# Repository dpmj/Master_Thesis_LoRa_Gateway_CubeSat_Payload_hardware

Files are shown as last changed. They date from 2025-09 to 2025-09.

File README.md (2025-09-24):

# Hardware design of a LoRa Gateway payload for CubeSat.

This repository contains the hardware design files from my first Master's Thesis in Electronic Systems Engineering at the Polytechnic University of Valencia, Spain, 2024. The thesis covers developing a LoRa communications payload for a CubeSat in Low Earth Orbit (LEO). The payload consists of two mPCIe LoRa gateway modules and a CubeSat-PC/104 motherboard, which serves as the electrical and mechanical interface with the rest of the satellite. An Electrical Ground Support Equipment (EGSE) auxiliary board provides test hardware for the payload by emulating interaction with the CubeSat. It also acts as a LoRa end-device to test the performance of the communications system.

This project has been superseded and continued in my other master's thesis: [Hardware design of a LoRa Gateway and in-orbit computing payload for CubeSat](https://github.com/dpmj/masters-thesis-lora-gateway-compute-module-cubesat-payload-pcb).

Third-party desing elements included in this repository are subject to the copyright of their respective owners.

```bibtex
@phdthesis{dpmj-master-thesis-2024,
    author = {{Del Pino Mena}, Juan},
    title = {Development of a {LoRa}-based communications payload for {CubeSat}},
    school = {Universitat Politècnica de València},
    year = {2024},
    month = {9},
    address = {València, Spain},
    type = {Master's thesis},
    url = {https://riunet.upv.es/handle/10251/209572},
    doi = {https://doi.org/10.5281/zenodo.13935118}
}
```

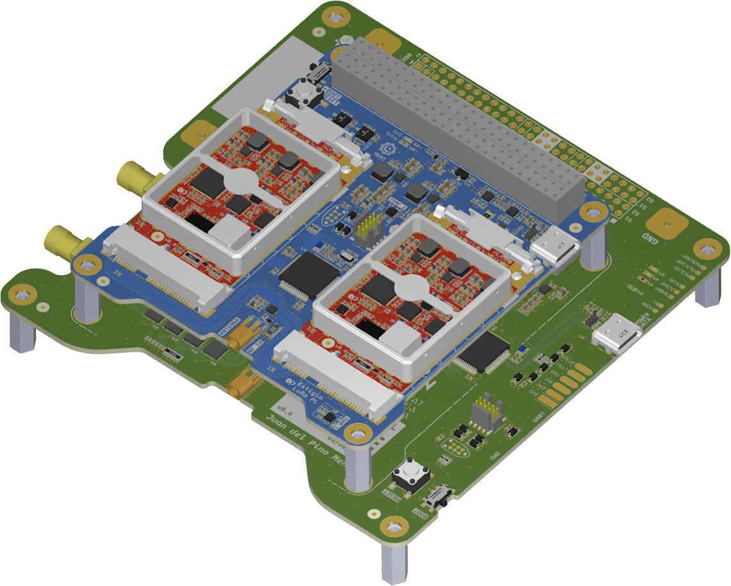
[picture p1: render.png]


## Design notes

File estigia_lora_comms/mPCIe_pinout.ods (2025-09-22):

Top side |  |  | Bottom side
N.º | PCIE | LORA SOM | N.º | PCIE | LORA SOM
1 | WAKE# | GND | 2 | 3.3V | 5V
3 | COEX1 | RFIO | 4 | GND | GND
5 | COEX2 | GND | 6 | 1.5V | NC
7 | CLKREQ# | NC | 8 | UIM_PWR | NC
9 | GND | GND | 10 | UIM_DATA | NC
11 | REFCLK- | NC | 12 | UIM_CLK | RADIO_CLK_OUT
13 | REFCLK+ | NC | 14 | UIM_RESET | RESET
15 | N/C or GND | GND | 16 | UIM_VPP | ENABLE
Mechanical key
17 | UIM_C8_RSV | NC | 18 | GND | GND
19 | UIM_C4_RSV | NC | 20 | W_DISABLE# | NC
21 | GND | GND | 22 | PERST# | NC
23 | PERn0 | NC | 24 | 3.3V | 5V
25 | PERp0 | NC | 26 | GND | GND
27 | GND | GND | 28 | +1.5V | NC
29 | GND | GND | 30 | SMB_CLK | I2C_SCL
31 | PETn0 | NC | 32 | SMB_DATA | I2C_SDA
33 | PETp0 | NC | 34 | GND | GND
35 | GND | GND | 36 | USB_D- | NC
37 | GND | GND | 38 | USB_D+ | NC
39 | 3.3V | 5V | 40 | GND | GND
41 | 3.3V | 5V | 42 | LED_WWAN# | PG1V2
43 | GND | GND | 44 | LED_WLAN# | PG3V3
45 | Reserved* | MCU_SPI_CLK | 46 | LED_WPAN# | PG3V9
47 | Reserved* | MCU_SPI_MISO | 48 | +1.5V | NC
49 | Reserved* | MCU_SPI_MOSI | 50 | GND | GND
51 | Reserved* | MCU_SPI_NSS | 52 | +3.3V | 5V

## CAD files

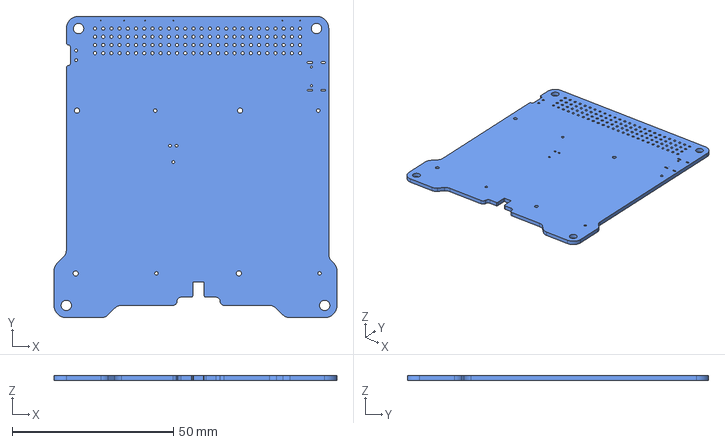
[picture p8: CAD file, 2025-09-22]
carrier/outputs/3D STEP/carrier_pcb_only.step
87.6 x 93.3 x 1.59 mm

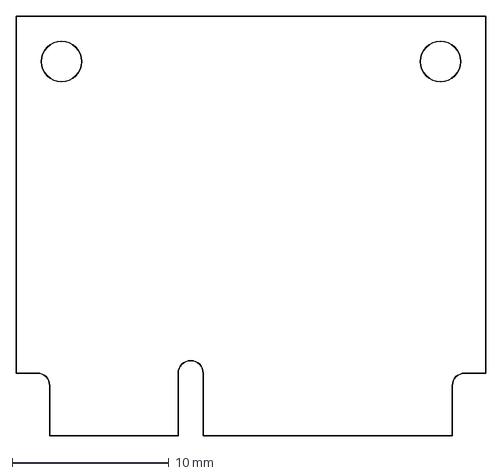
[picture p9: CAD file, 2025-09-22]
estigia_lora_comms/assets/templates/mini-pcie-card-template-master/MiniPCIe.dxf
30.0 x 26.8 mm

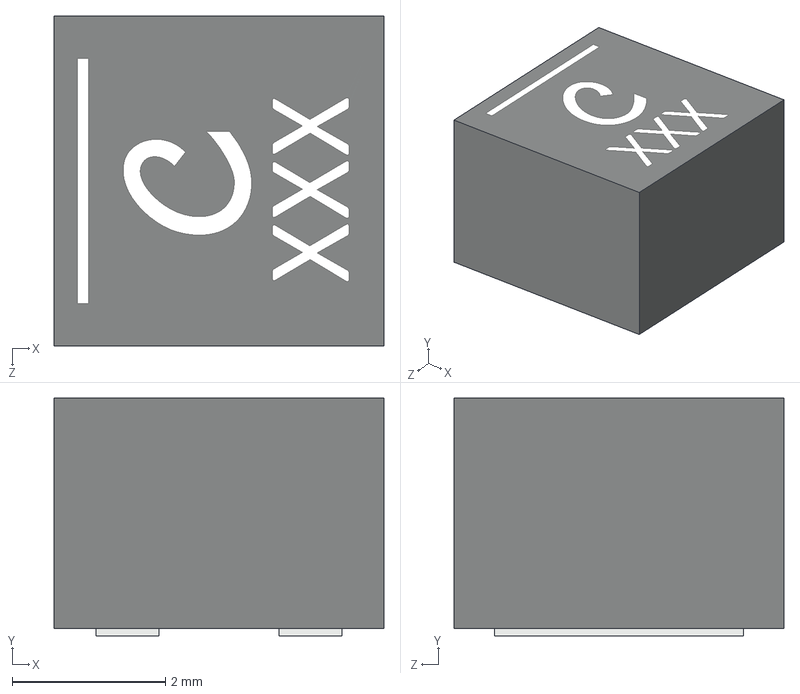
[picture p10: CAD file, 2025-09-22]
estigia_lora_comms/library-common/models/Coilcraft-XGL4030/Coilcraft-XGL4030.step
4.30 x 3.10 x 4.30 mm

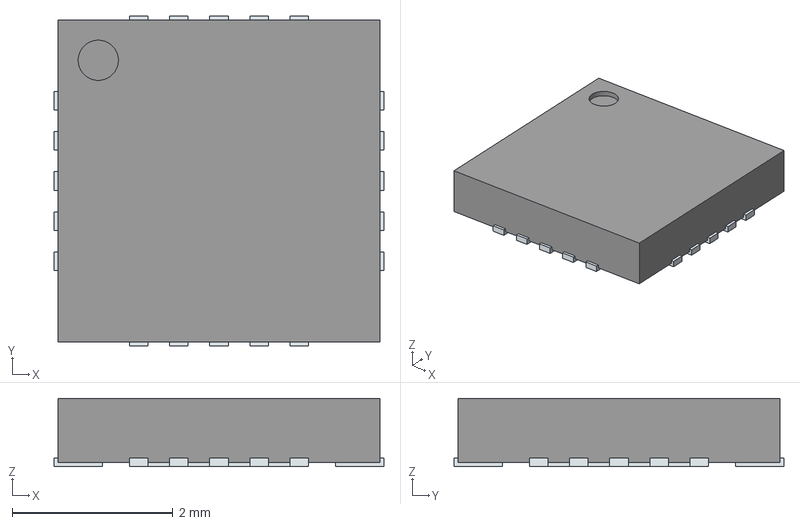
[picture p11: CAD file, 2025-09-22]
estigia_lora_comms/library-common/models/DG983-2/DG983-2.stp
4.10 x 4.10 x 0.85 mm
ThermalPin
PinsArrayLR
PinsArrayTB

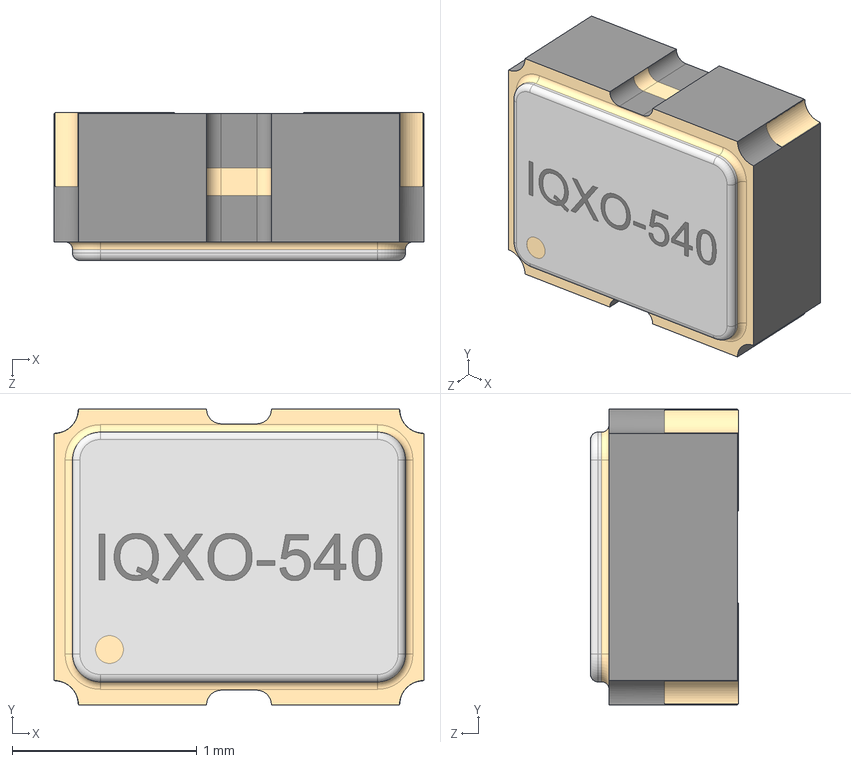
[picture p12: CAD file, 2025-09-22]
estigia_lora_comms/library-common/models/FT2MNTUM/IQXO-540.step
2.00 x 1.60 x 0.8 mm

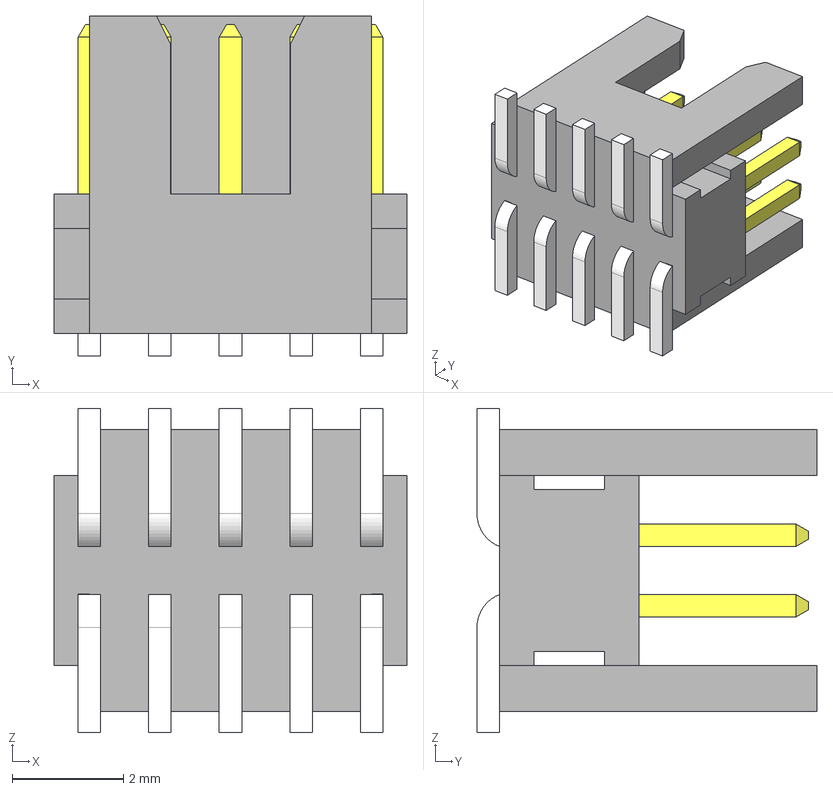
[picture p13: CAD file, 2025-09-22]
estigia_lora_comms/library-common/models/FTSH-105/FTSH-105-01-L-DV.stp
6.35 x 6.12 x 5.84 mm
_FTSH-105-01-F-DV-K_body
_FTSH-105-01-F-DV-K_pins1
_FTSH-105-01-F-DV-K_pins2

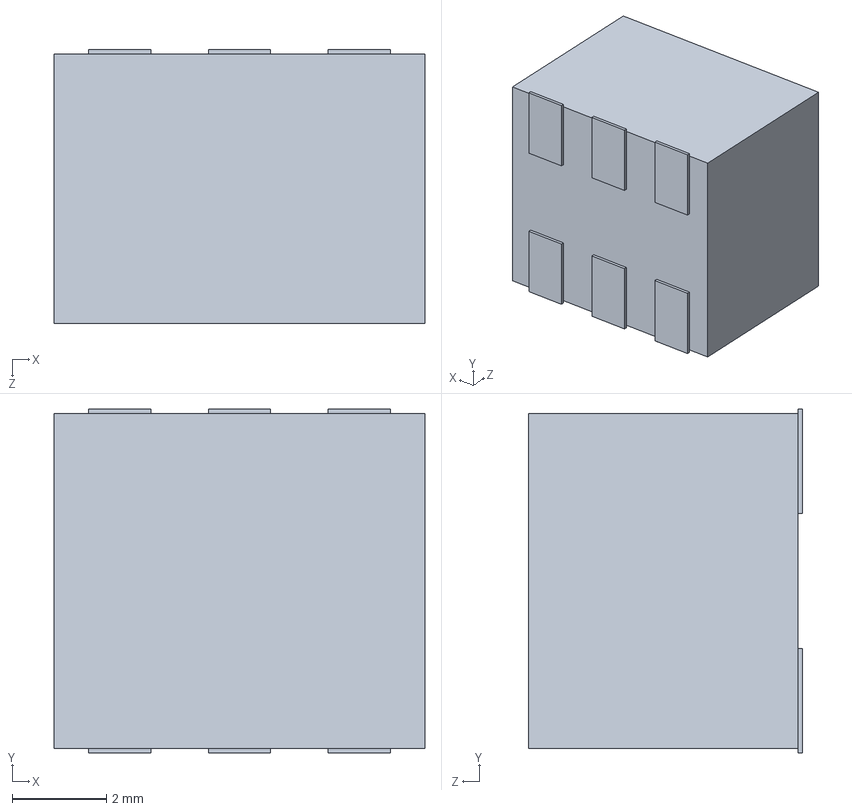
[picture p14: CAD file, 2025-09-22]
estigia_lora_comms/library-common/models/JPS-2-1N+/JPS-2-1N+.STEP
7.87 x 7.29 x 5.82 mm

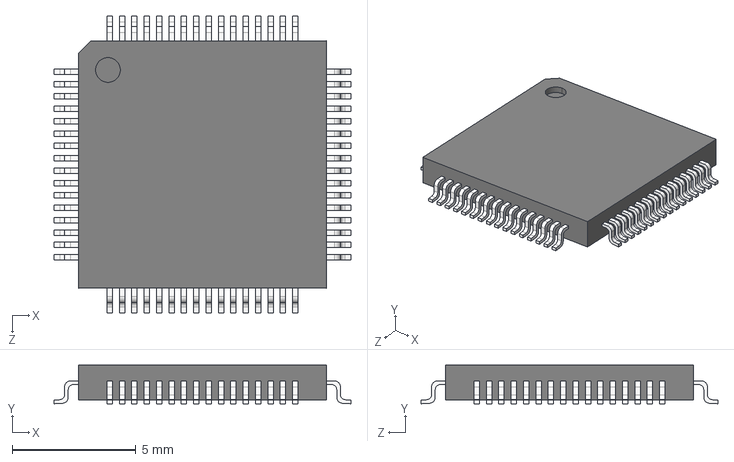
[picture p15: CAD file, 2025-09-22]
estigia_lora_comms/library-common/models/LQFP64/LQFP64.step
12.0 x 1.56 x 12.0 mm

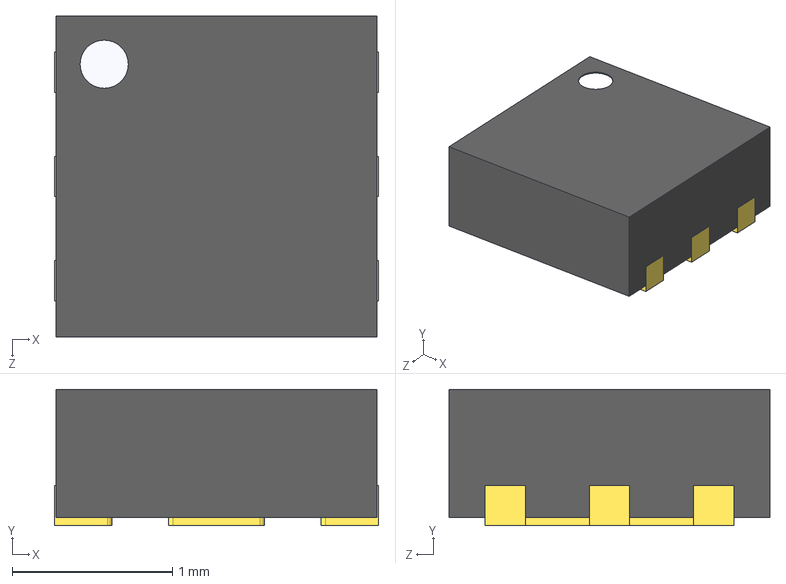
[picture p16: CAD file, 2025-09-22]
estigia_lora_comms/library-common/models/MC1630/MC1630.step
2.02 x 0.85 x 2.00 mm

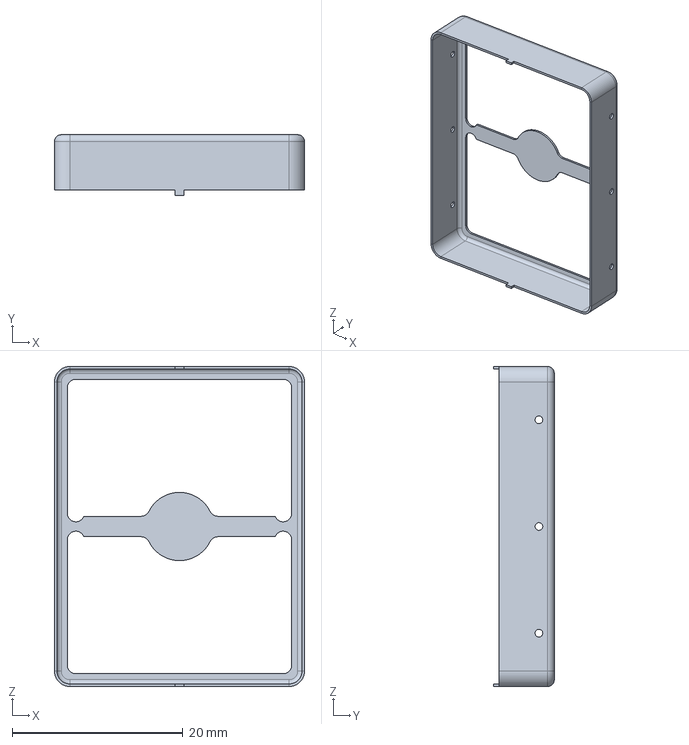
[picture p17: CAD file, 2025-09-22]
estigia_lora_comms/library-common/models/MS375-10F/ms375-10f.stp
29.3 x 7.10 x 37.5 mm

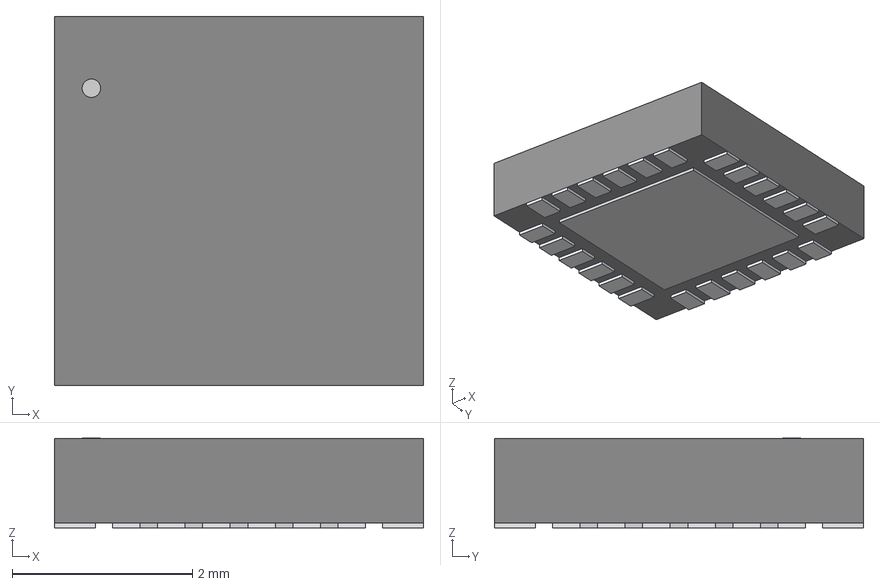
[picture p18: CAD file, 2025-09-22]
estigia_lora_comms/library-common/models/QFN-24/QFN_0IMLTRT_SEM.step
4.09 x 4.09 x 0.993 mm

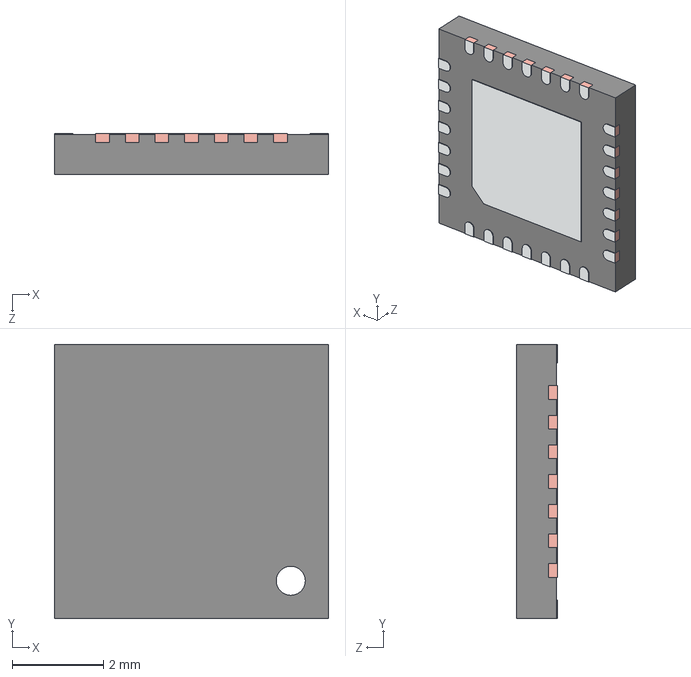
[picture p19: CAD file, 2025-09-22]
estigia_lora_comms/library-common/models/QFN-28/QFN28_0_65.step
6.00 x 6.00 x 0.9 mm

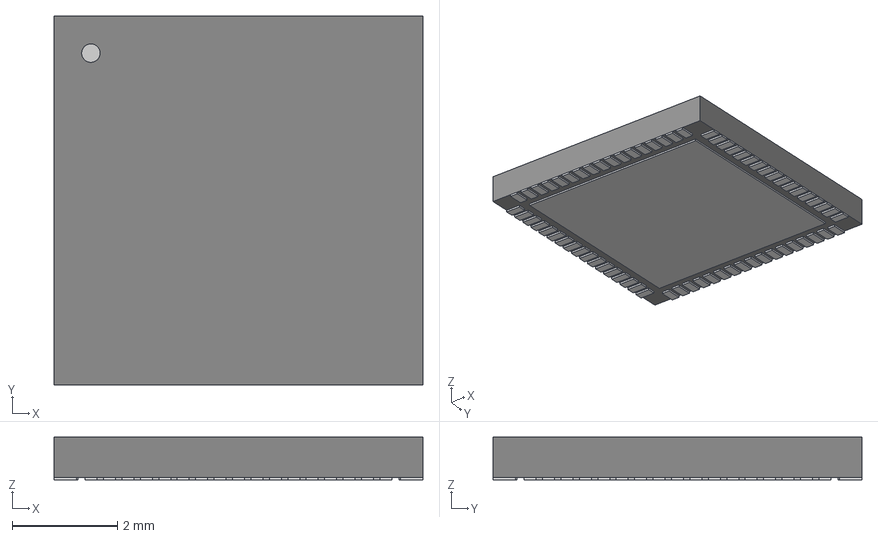
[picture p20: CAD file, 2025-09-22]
estigia_lora_comms/library-common/models/QFN-68/QFN68_7X7_SEM.step
7.01 x 7.01 x 0.815 mm

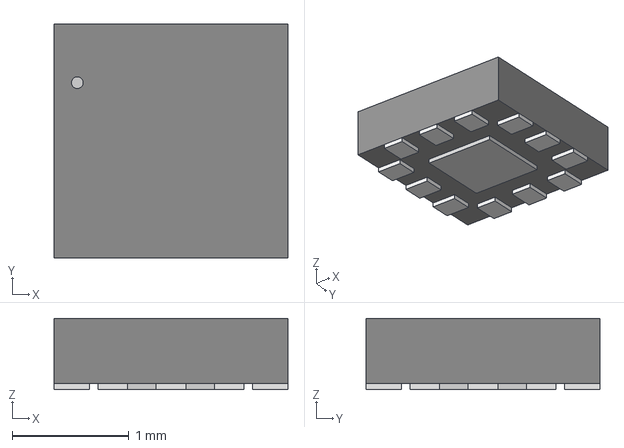
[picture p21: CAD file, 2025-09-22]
estigia_lora_comms/library-common/models/SKY13330_397LF/QFN_330-397LF_SKY.step
2.01 x 2.01 x 0.612 mm

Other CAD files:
estigia_lora_comms/library-common/models/TXB0104NMN/TXB0104NMNR2.SLDASM
estigia_lora_comms/library-common/models/TXB0104NMN/TXB0104NMNR3.SLDASM
estigia_lora_comms/library-common/models/SMA/sma_straight.stp
estigia_lora_comms/library-common/models/SOT-23-8-INA232BIDDFR/INA232BIDDFR.stp
estigia_lora_comms/library-common/models/JPS-2-1N+/Body.stp.STEP
estigia_lora_comms/library-common/models/JPS-2-1N+/JPS-2-1N+.SLDASM
estigia_lora_comms/library-common/models/JPS-2-1N+/JPS-2-1N+.SLDPRT
estigia_lora_comms/library-common/models/JPS-2-1N+/JPS-2-1N+.stp
estigia_lora_comms/library-common/models/JPS-2-1N+/JPS-2-1N+.stp.STEP
estigia_lora_comms/library-common/models/JPS-2-1N+/JPS-2-1N+_2.SLDPRT
estigia_lora_comms/library-common/models/JPS-2-1N+/JPS-2-1N+_2.STEP
estigia_lora_comms/library-common/models/JPS-2-1N+/Pins.stp.STEP
estigia_lora_comms/library-common/models/MMCX/66012202111305.stp
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

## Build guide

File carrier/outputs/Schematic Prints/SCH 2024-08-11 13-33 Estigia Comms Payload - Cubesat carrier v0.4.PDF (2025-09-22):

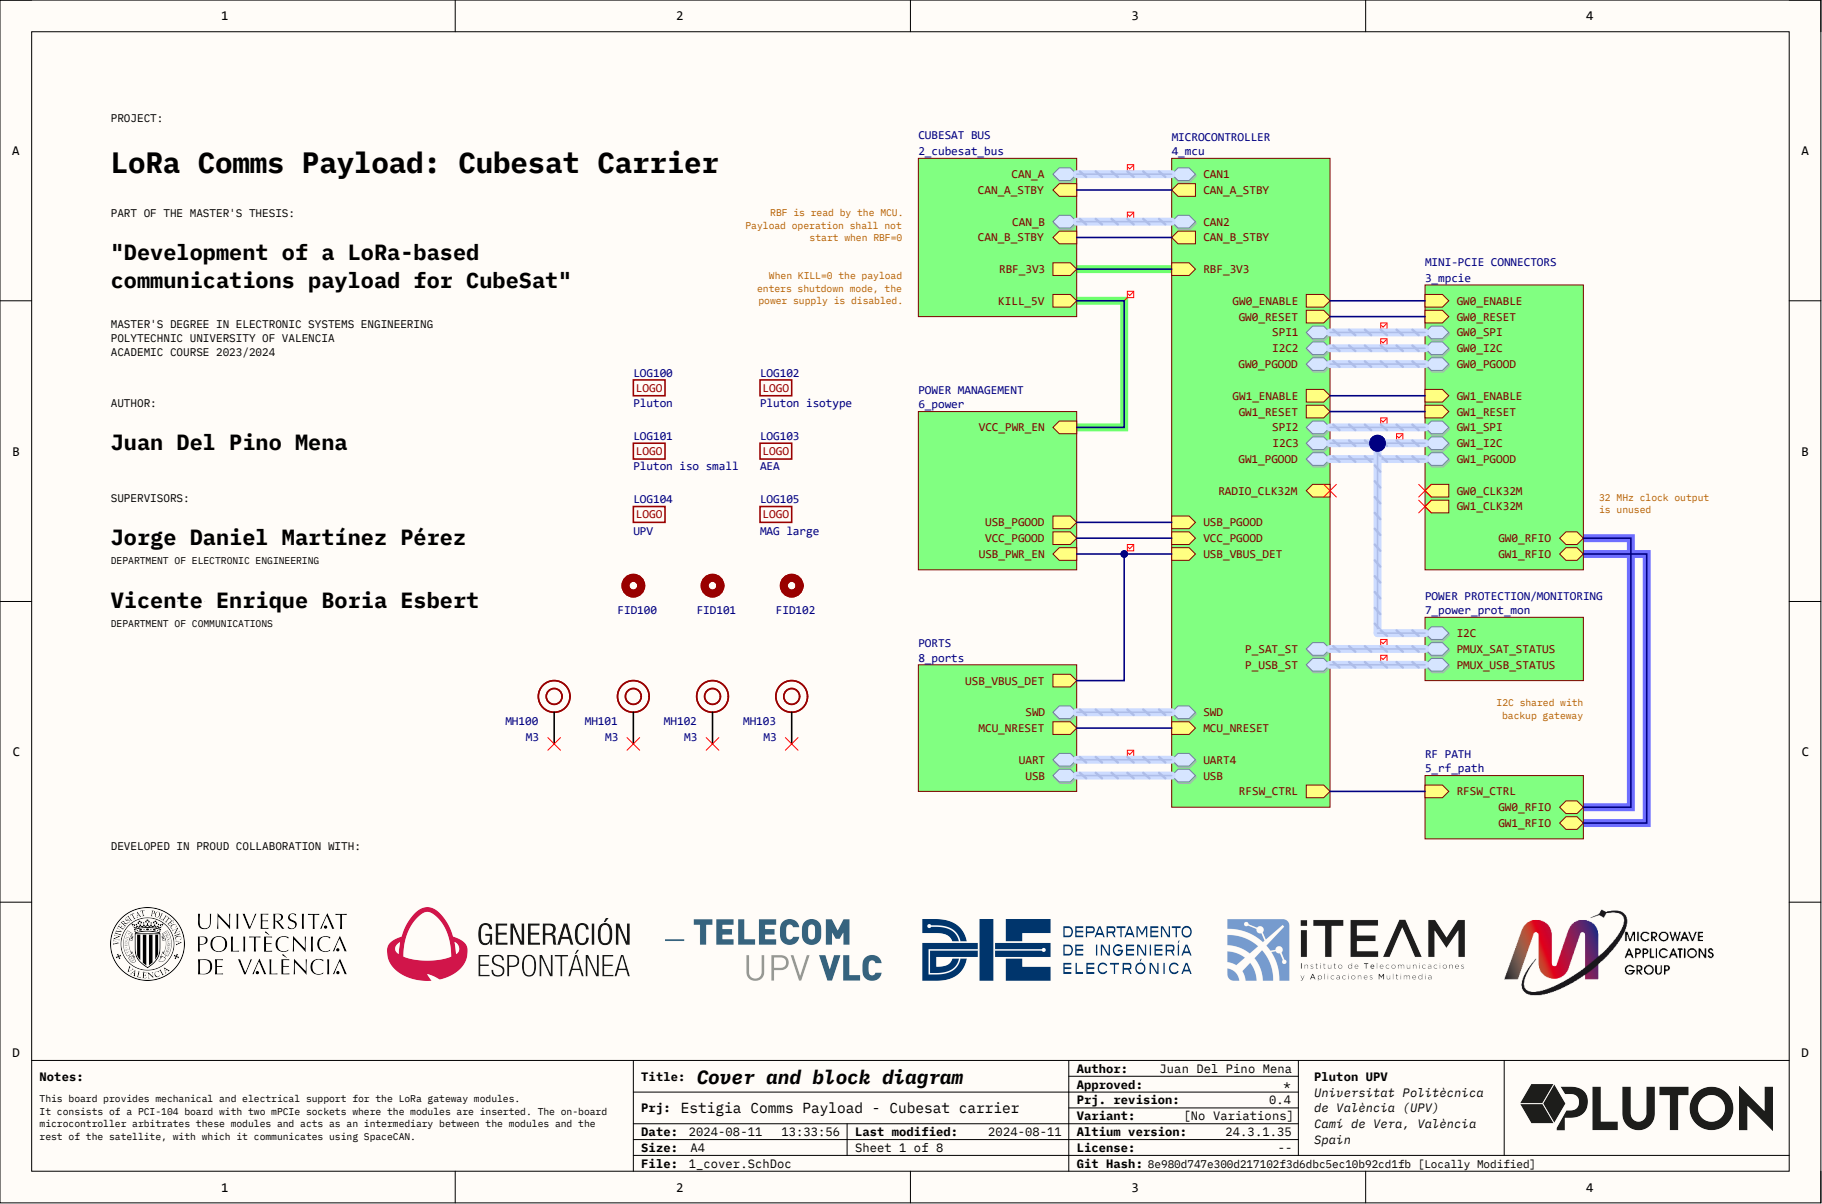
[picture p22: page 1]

PROJECT:
LoRa Comms Payload: Cubesat Carrier

PART OF THE MASTER'S THESIS:
"Development of a LoRa-based
communications payload for CubeSat"

RBF is read by the MCU.
Payload operation shall not

When KILL=0 the payload
enters shutdown mode, the
power supply is disabled.

MASTER'S DEGREE IN ELECTRONIC SYSTEMS ENGINEERING
POLYTECHNIC UNIVERSITY OF VALENCIA
ACADEMIC COURSE 2023/2024

AUTHOR:
Juan Del Pino Mena

SUPERVISORS:
Jorge Daniel Martínez Pérez

DEPARTMENT OF ELECTRONIC ENGINEERING
Vicent eE nrique Boria Esbert

DEVELOPED IN PROUD COLLABORATION WITH:

This board provides mechanical and electrical support for the LoRa gateway modules.
It consists of a PCI-104 board with two mPCIe sockets where the modules are inserted. The on-board
microcontroller arbitrates these modules and acts as an intermediary between the modules and the
rest of the satellite, with which it communicates using SpaceCAN.

Prj: Estigia Comms Payload - Cubesat carrier

License:
Git Hash: 8e980d747e300d217102f3d6dbc5ec10b92cd1fb [Locally Modified]

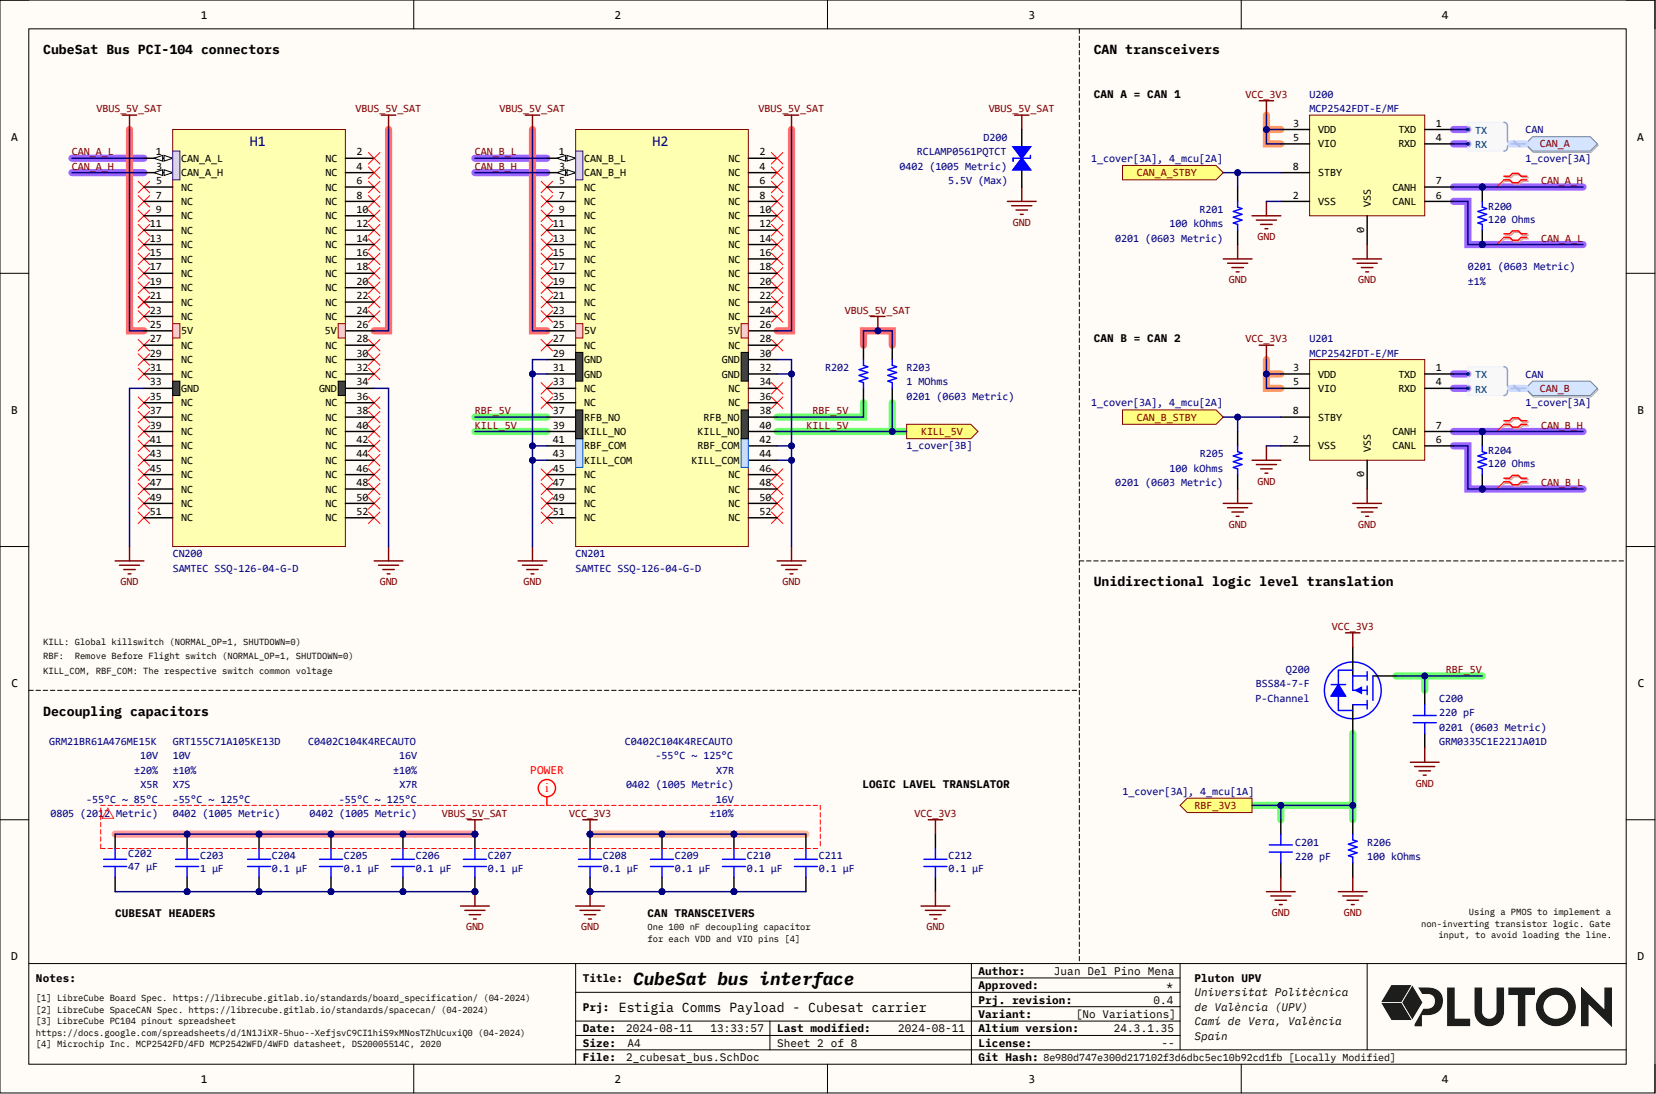
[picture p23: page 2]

Unidirectional logic level translation

KILL: Global killswitch (NORMAL_OP=1, SHUTDOWN=0)
RBF: Remove Before Flight switch (NORMAL_OP=1, SHUTDOWN=0)
KILL_COM, RBF_COM: The respective switch common voltage

non-inverting transistor logic. Gate
input, to avoid loading the line.

Using a PMOS to implement a

One 100 nF decoupling capacitor
for each VDD and VIO pins [4]

Juan Del Pino Mena

[1] LibreCube Board Spec. https://librecube.gitlab.io/standards/board_specification/ (04-2024)
[2] LibreCube SpaceCAN Spec. https://librecube.gitlab.io/standards/spacecan/ (04-2024)
[3] LibreCube PC104 pinout spreadsheet
https://docs.google.com/spreadsheets/d/1N1JiXR-5huo--XefjsvC9CI1hiS9xMNosTZhUcuxiQ0 (04-2024)
[4] Microchip Inc. MCP2542FD/4FD MCP2542WFD/4WFD datasheet, DS20005514C, 2020

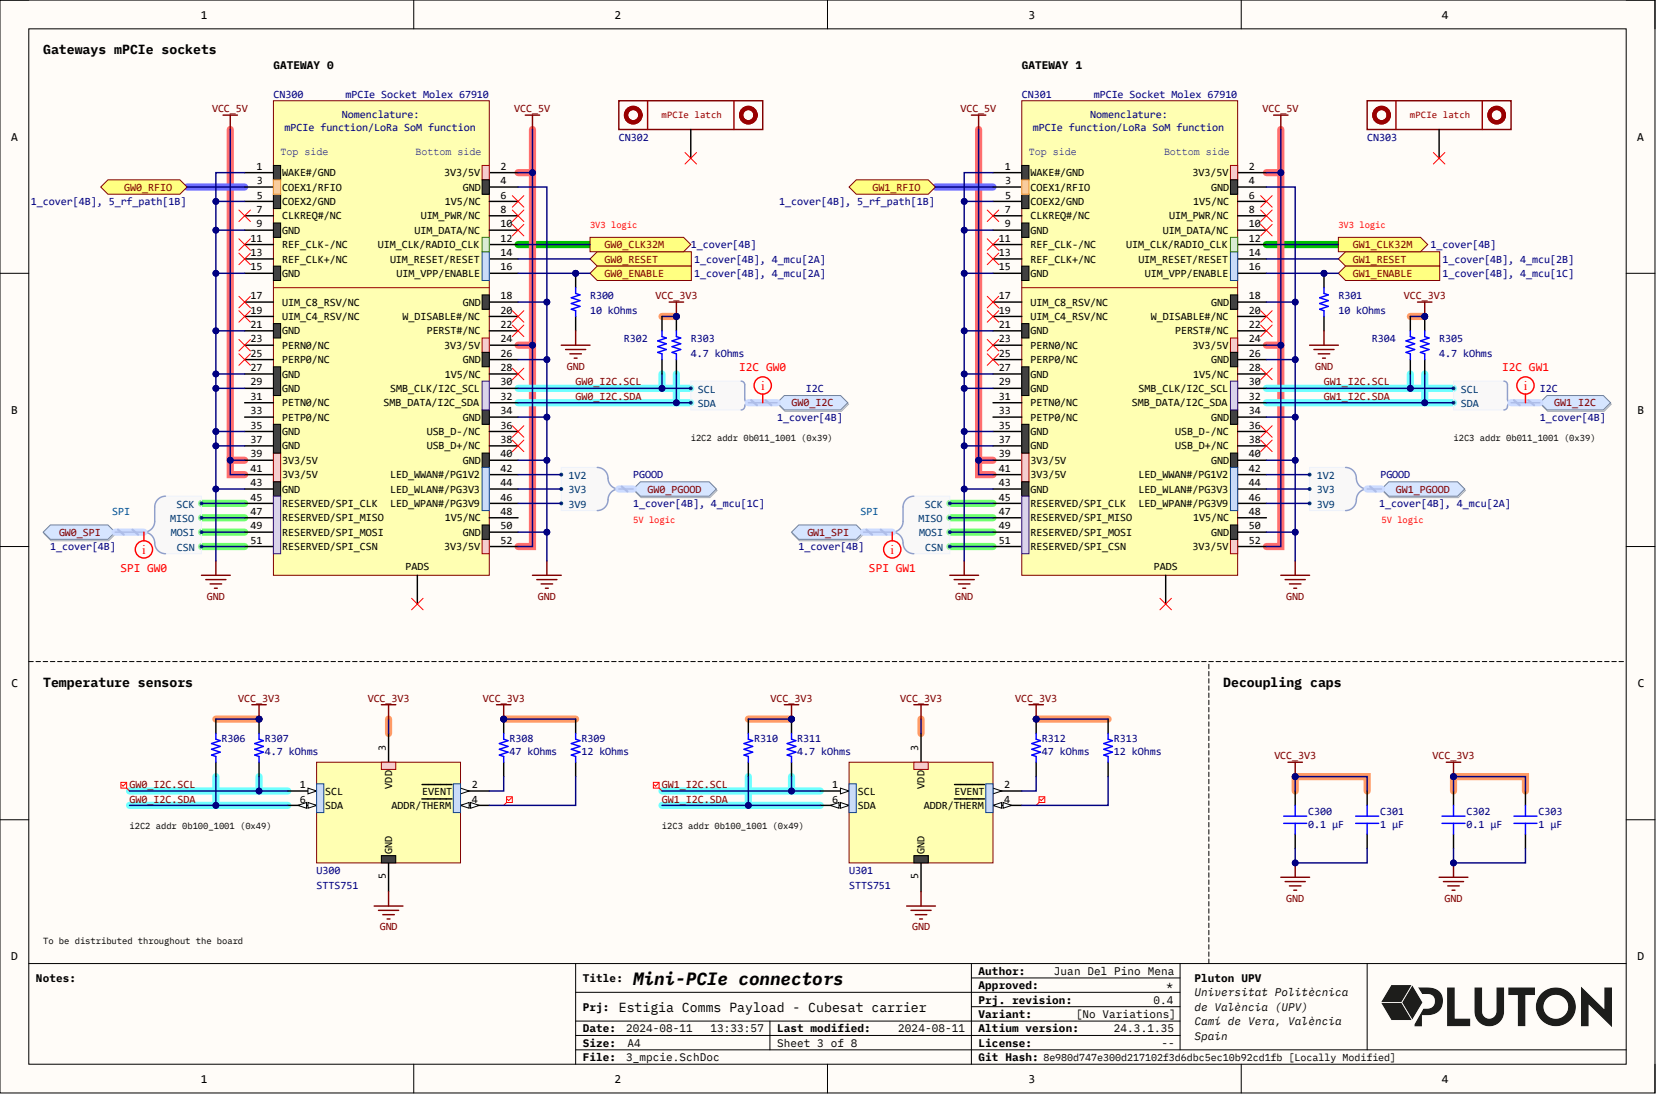
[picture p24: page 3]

mPCIe function/LoRa SoM function

To be distributed throughout the board

Juan Del Pino Mena

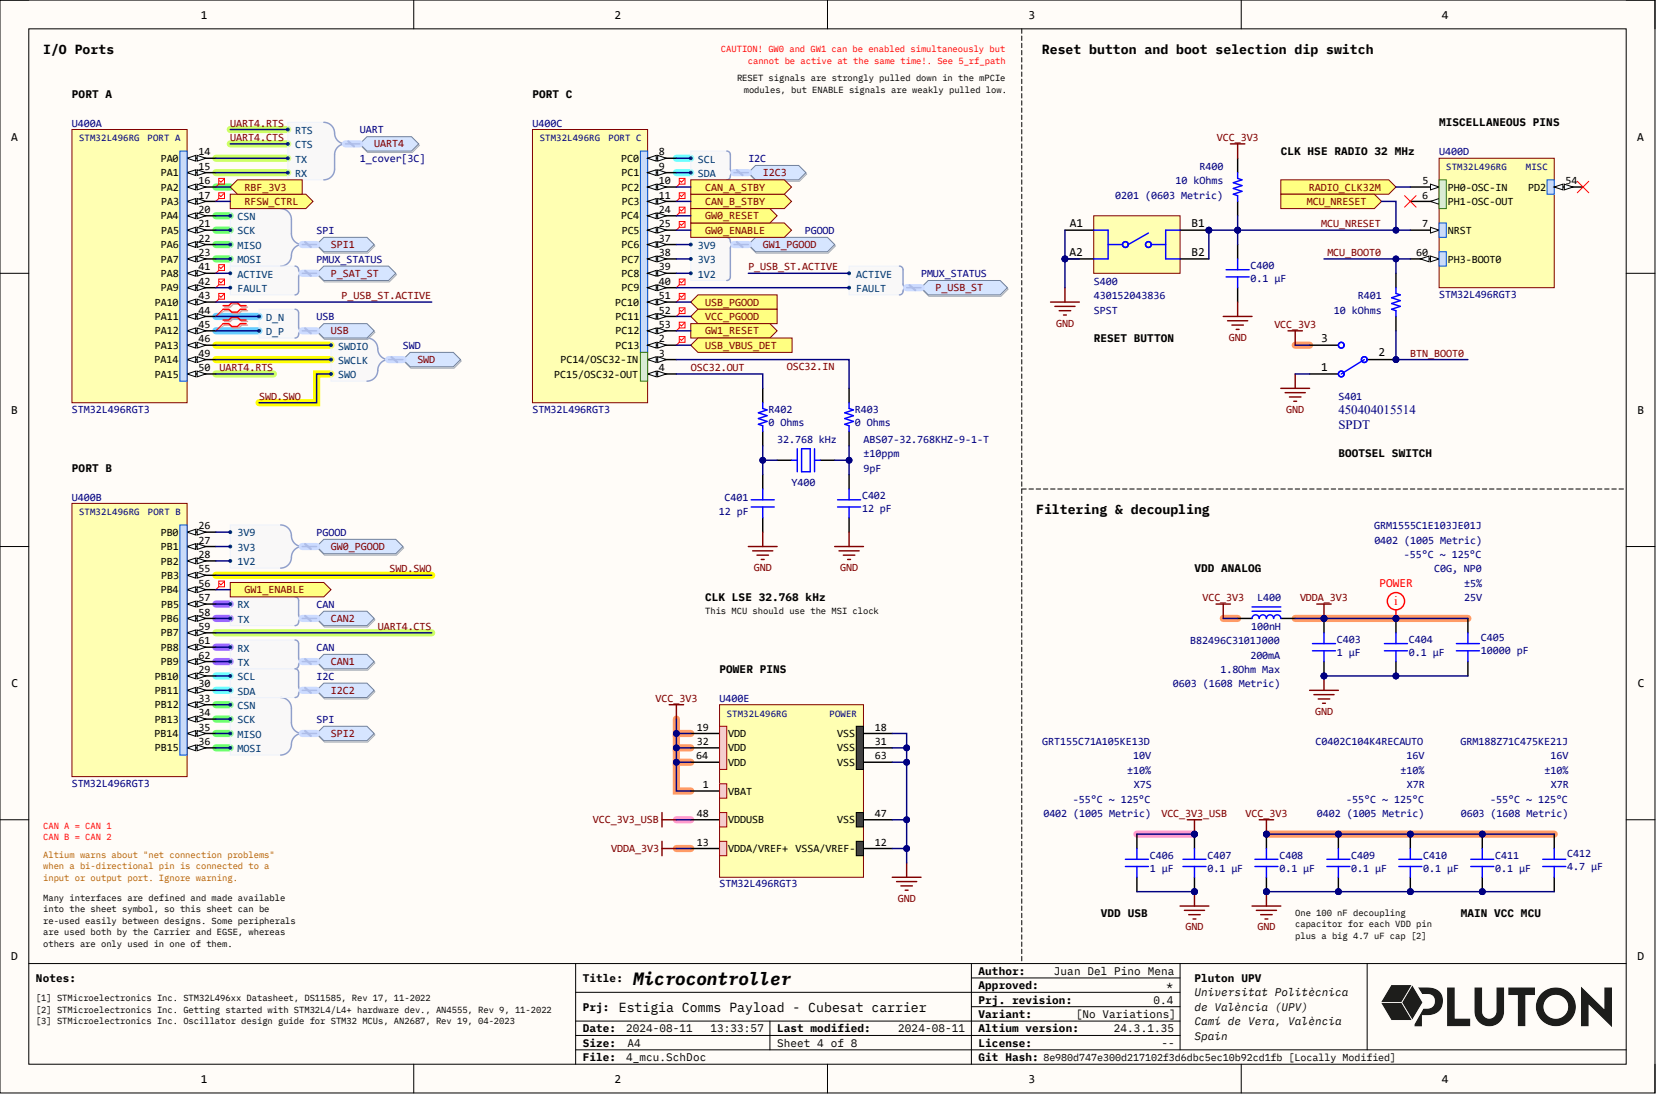
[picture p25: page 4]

CAUTION! GW0 and GW1 can be enabled simultaneously but
cannot be active at the same time!. See 5_rf_path

Reset button and boot selection dip switch

RESET signals are strongly pulled down in the mPCIe
modules, but ENABLE signals are weakly pulled low.

CLK HSE RADIO 32 MHz

CLK LSE 32.768 kHz
This MCU should use the MSI clock

Altium warns about "net connection problems"
when a bi-directional pin is connected to a
input or output port. Ignore warning.

Many interfaces are defined and made available
into the sheet symbol, so this sheet can be
re-used easily between designs. Some peripherals
are used both by the Carrier and EGSE, whereas
others are only used in one of them.

One 100 nF decoupling
capacitor for each VDD pin
plus a big 4.7 uF cap [2]

Juan Del Pino Mena

[1] STMicroelectronics Inc. STM32L496xx Datasheet, DS11585, Rev 17, 11-2022
[2] STMicroelectronics Inc. Getting started with STM32L4/L4+ hardware dev., AN4555, Rev 9, 11-2022
[3] STMicroelectronics Inc. Oscillator design guide for STM32 MCUs, AN2687, Rev 19, 04-2023

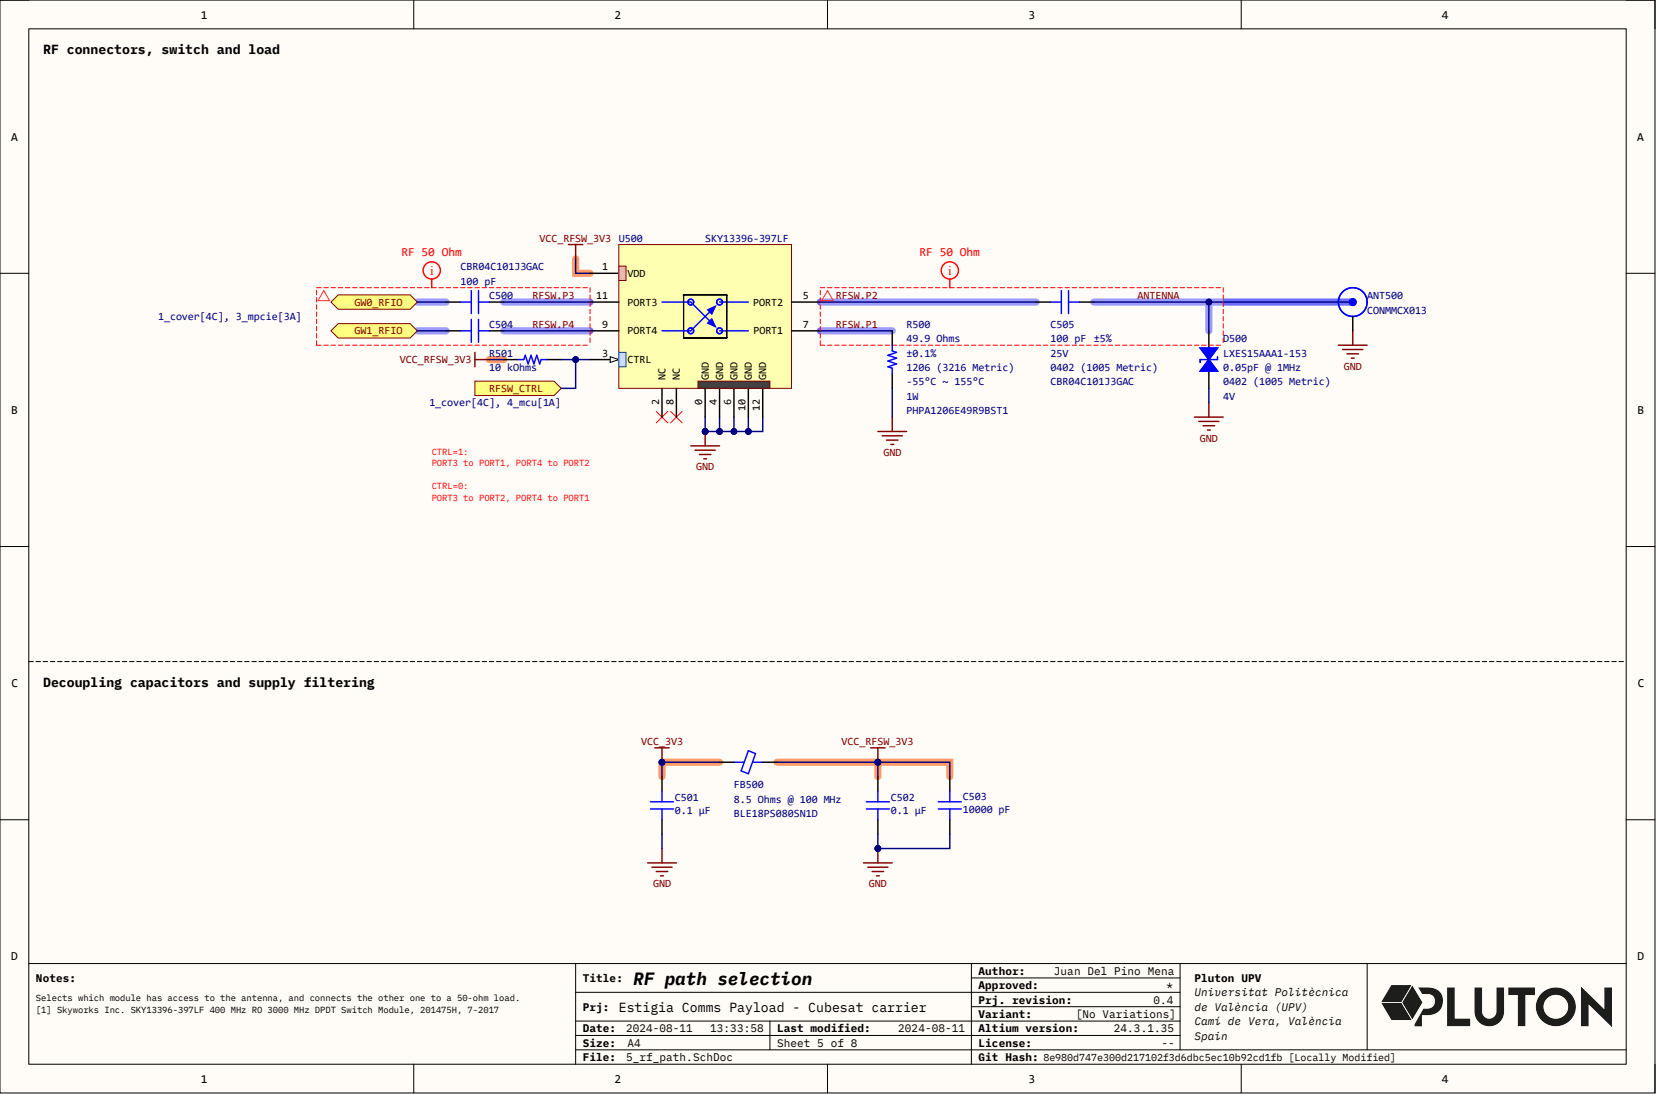
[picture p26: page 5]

RF connectors, switch and load

Decoupling capacitors and supply filtering

Juan Del Pino Mena

Selects which module has access to the antenna, and connects the other one to a 50-ohm load.
[1] Skyworks Inc. SKY13396-397LF 400 MHz RO 3000 MHz DPDT Switch Module, 201475H, 7-2017

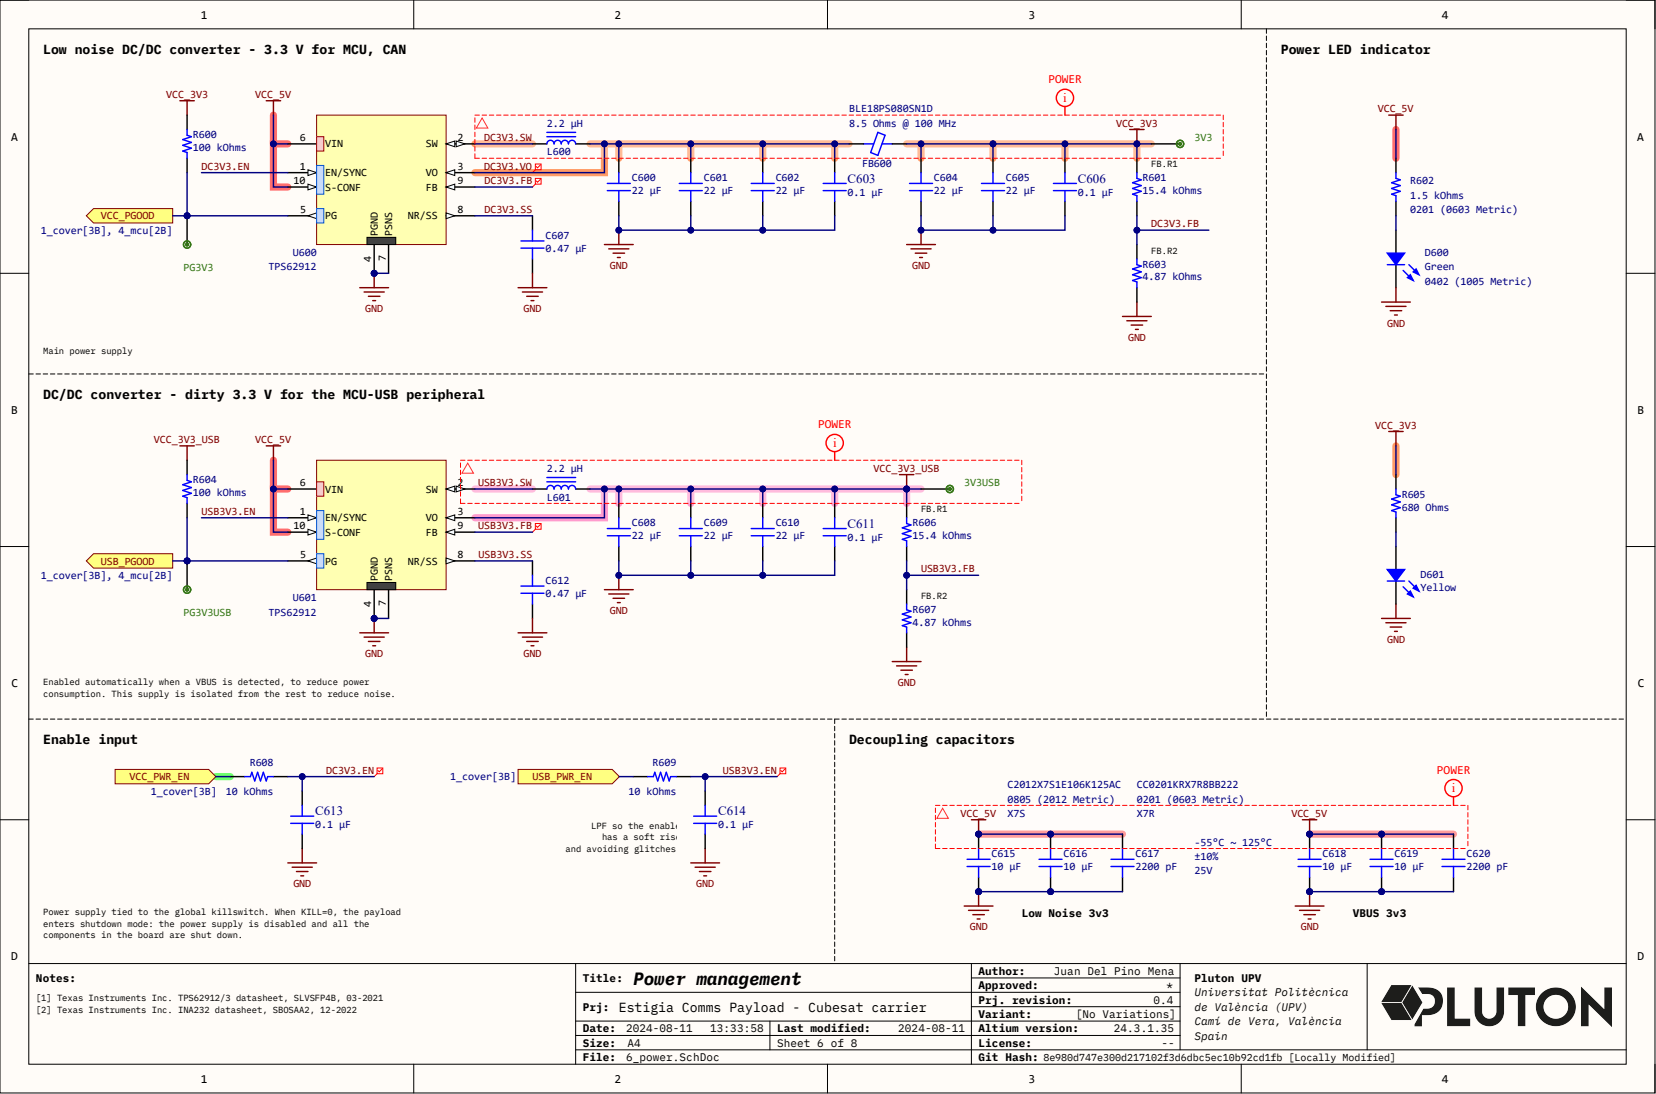
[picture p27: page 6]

Low noise DC/DC converter - 3.3 V for MCU, CAN

2.2 µH 8.5 Ohms @ 100 MHz VCC_3V3

DC/DC converter - dirty 3.3 V for the MCU-USB peripheral

Enabled automatically when a VBUS is detected, to reduce power

consumption. This supply is isolated from the rest to reduce noise.

LPF so the enable
has a soft rise

Power supply tied to the global killswitch. When KILL=0, the payload
enters shutdown mode: the power supply is disabled and all the
components in the board are shut down.

Juan Del Pino Mena

[1] Texas Instruments Inc. TPS62912/3 datasheet, SLVSFP4B, 03-2021
[2] Texas Instruments Inc. INA232 datasheet, SBOSAA2, 12-2022

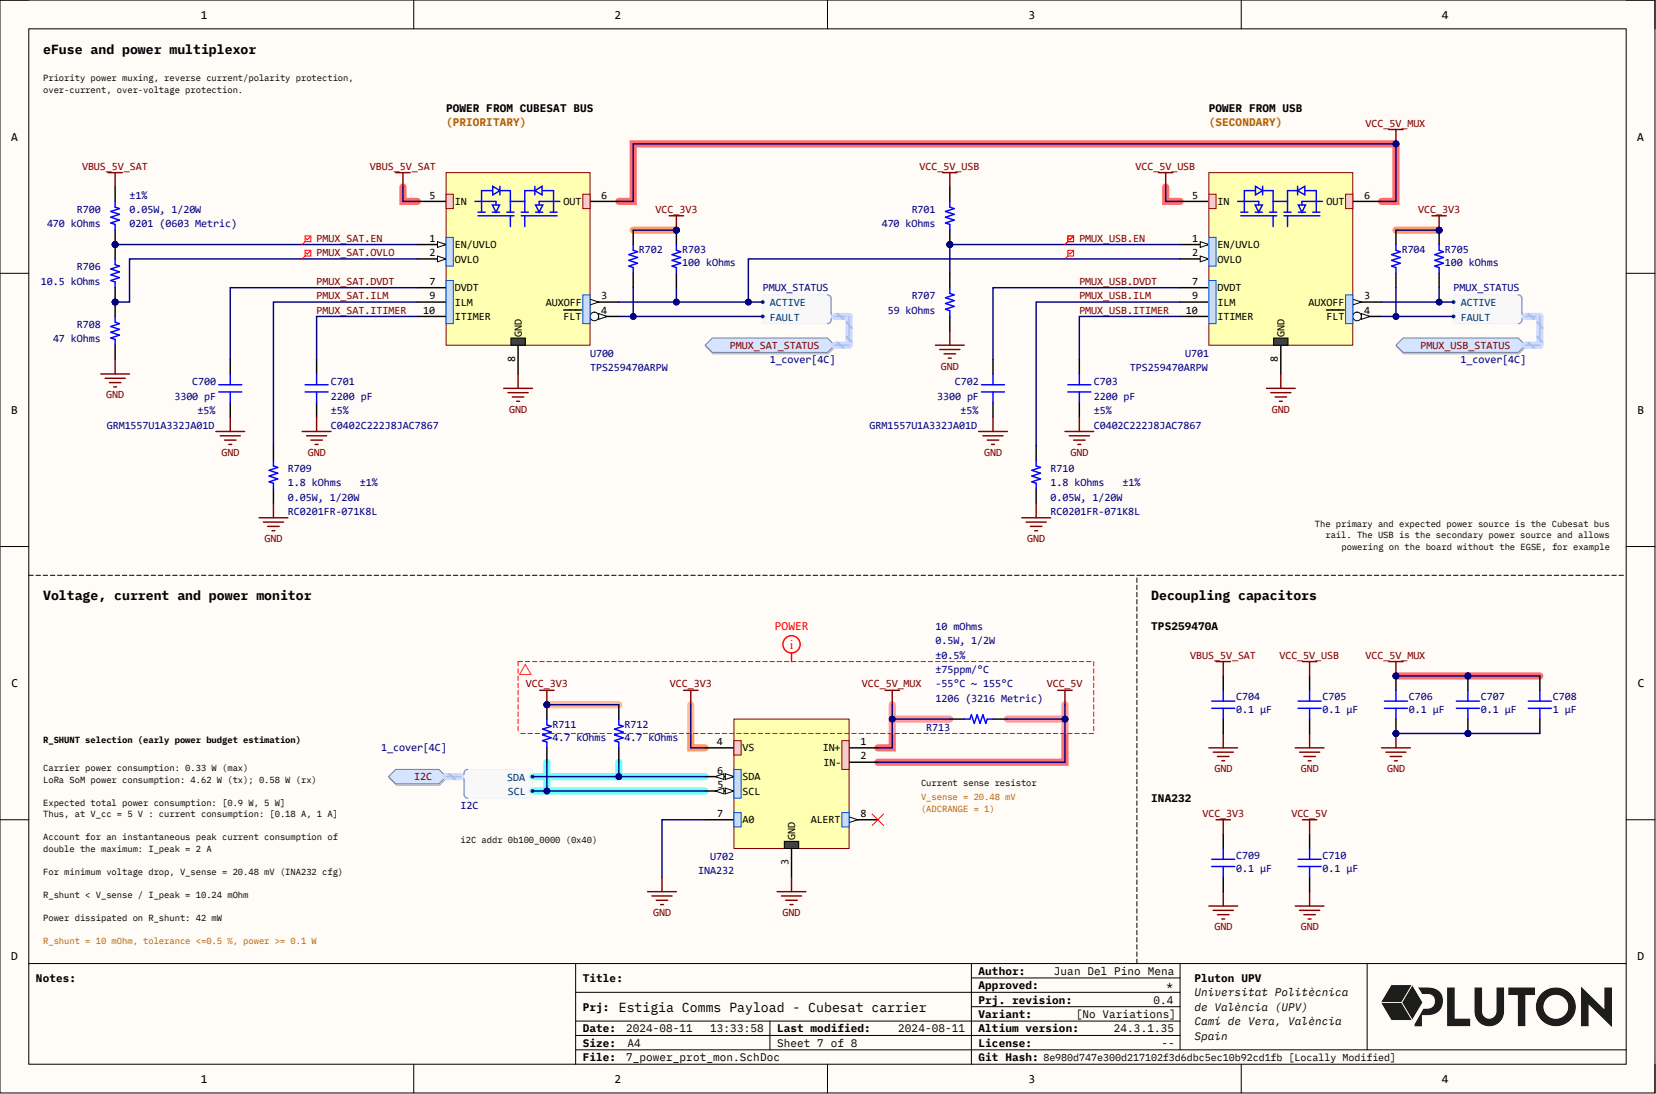
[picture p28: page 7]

eFuse and power multiplexor

Priority power muxing, reverse current/polarity protection,
over-current, over-voltage protection.

POWER FROM CUBESAT BUS
(PRIORITARY)

The primary and expected power source is the Cubesat bus
rail. The USB is the secondary power source and allows
powering on the board without the EGSE, for example

Voltage, current and power monitor

R_SHUNT selection (early power budget estimation)

Carrier power consumption: 0.33 W (max)
LoRa SoM power consumption: 4.62 W (tx); 0.58 W (rx)

Expected total power consumption: [0.9 W, 5 W]
Thus, at V_cc = 5 V : current consumption: [0.18 A, 1 A]

Account for an instantaneous peak current consumption of
double the maximum: I_peak = 2 A

For minimum voltage drop, V_sense = 20.48 mV (INA232 cfg)

Power dissipated on R_shunt: 42 mW

Juan Del Pino Mena

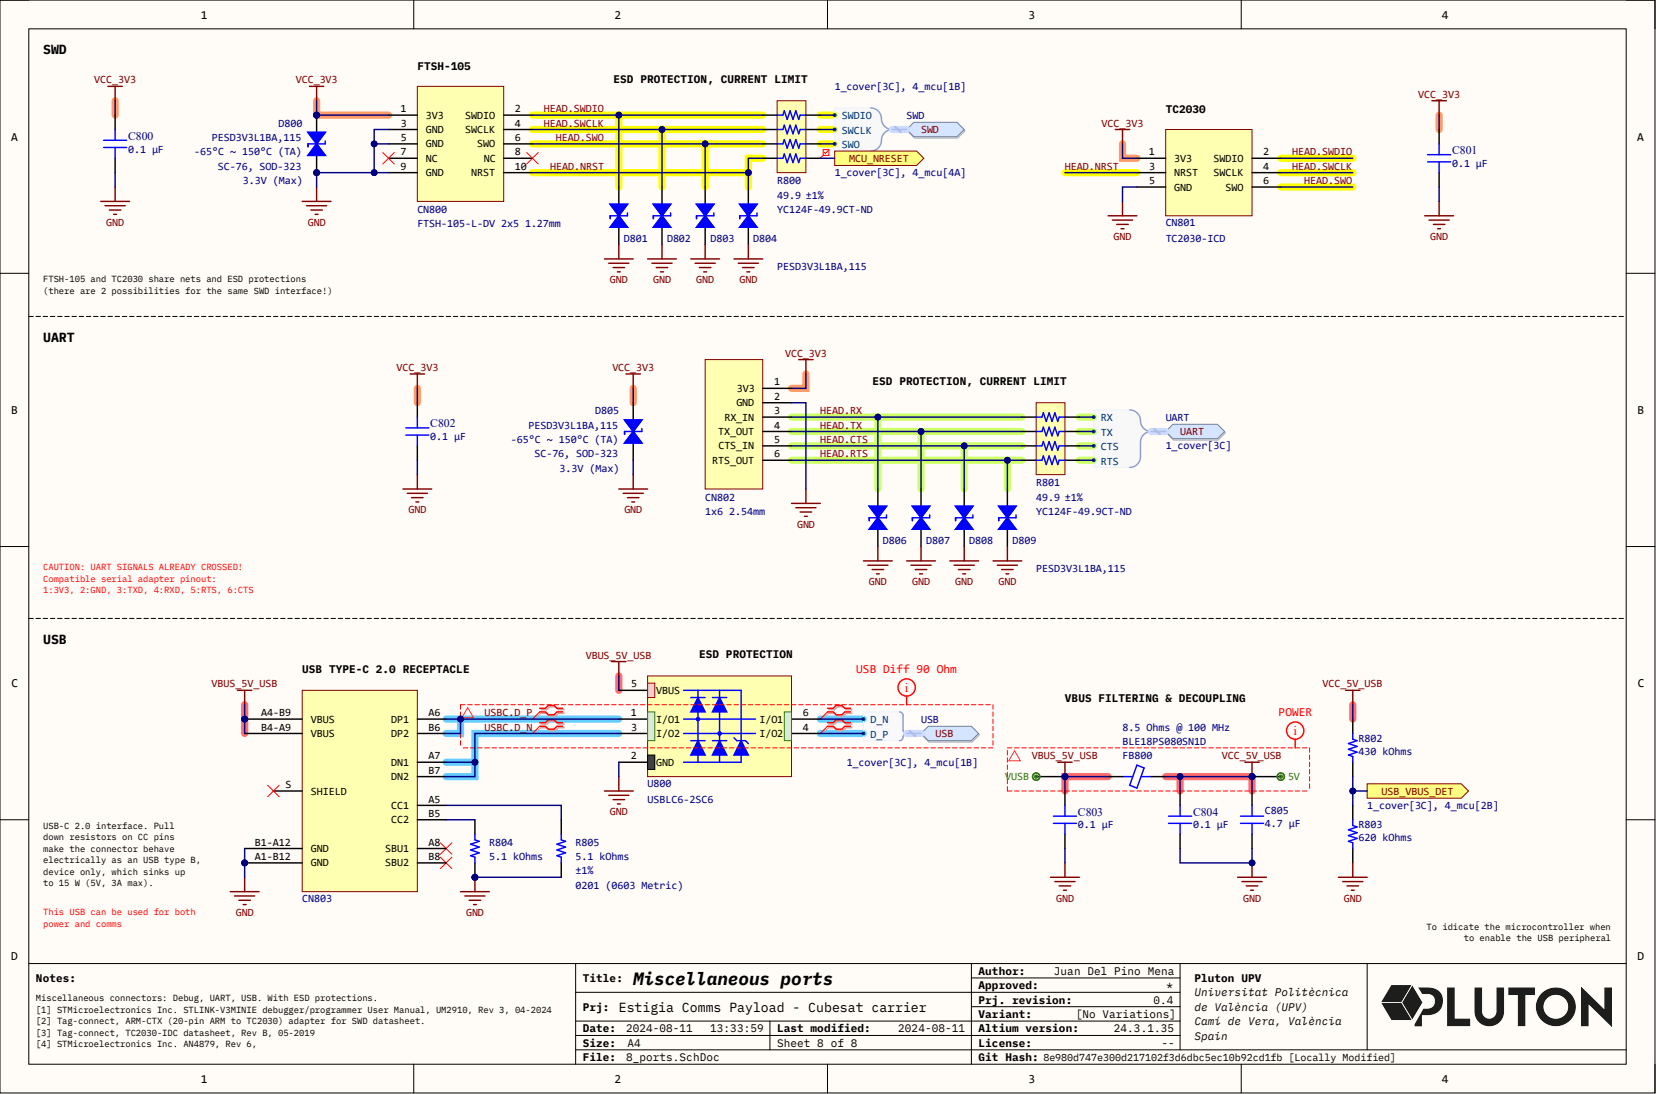
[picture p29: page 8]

ESD PROTECTION, CURRENT LIMIT

FTSH-105 and TC2030 share nets and ESD protections
(there are 2 possibilities for the same SWD interface!)

CAUTION: UART SIGNALS ALREADY CROSSED!
Compatible serial adapter pinout:
1:3V3, 2:GND, 3:TXD, 4:RXD, 5:RTS, 6:CTS

USBC.D_P | | | USB D_P

VBUS B4-A9 | USBC.D_N

USB-C 2.0 interface. Pull
down resistors on CC pins
make the connector behave
electrically as an USB type B,
device only, which sinks up
to 15 W (5V, 3A max).

This USB can be used for both
power and comms

To idicate the microcontroller when

to enable the USB peripheral

Juan Del Pino Mena

Miscellaneous connectors: Debug, UART, USB. With ESD protections.
[1] STMicroelectronics Inc. STLINK-V3MINIE debugger/programmer User Manual, UM2910, Rev 3, 04-2024
[2] Tag-connect, ARM-CTX (20-pin ARM to TC2030) adapter for SWD datasheet.
[3] Tag-connect, TC2030-IDC datasheet, Rev B, 05-2019
[4] STMicroelectronics Inc. AN4879, Rev 6,

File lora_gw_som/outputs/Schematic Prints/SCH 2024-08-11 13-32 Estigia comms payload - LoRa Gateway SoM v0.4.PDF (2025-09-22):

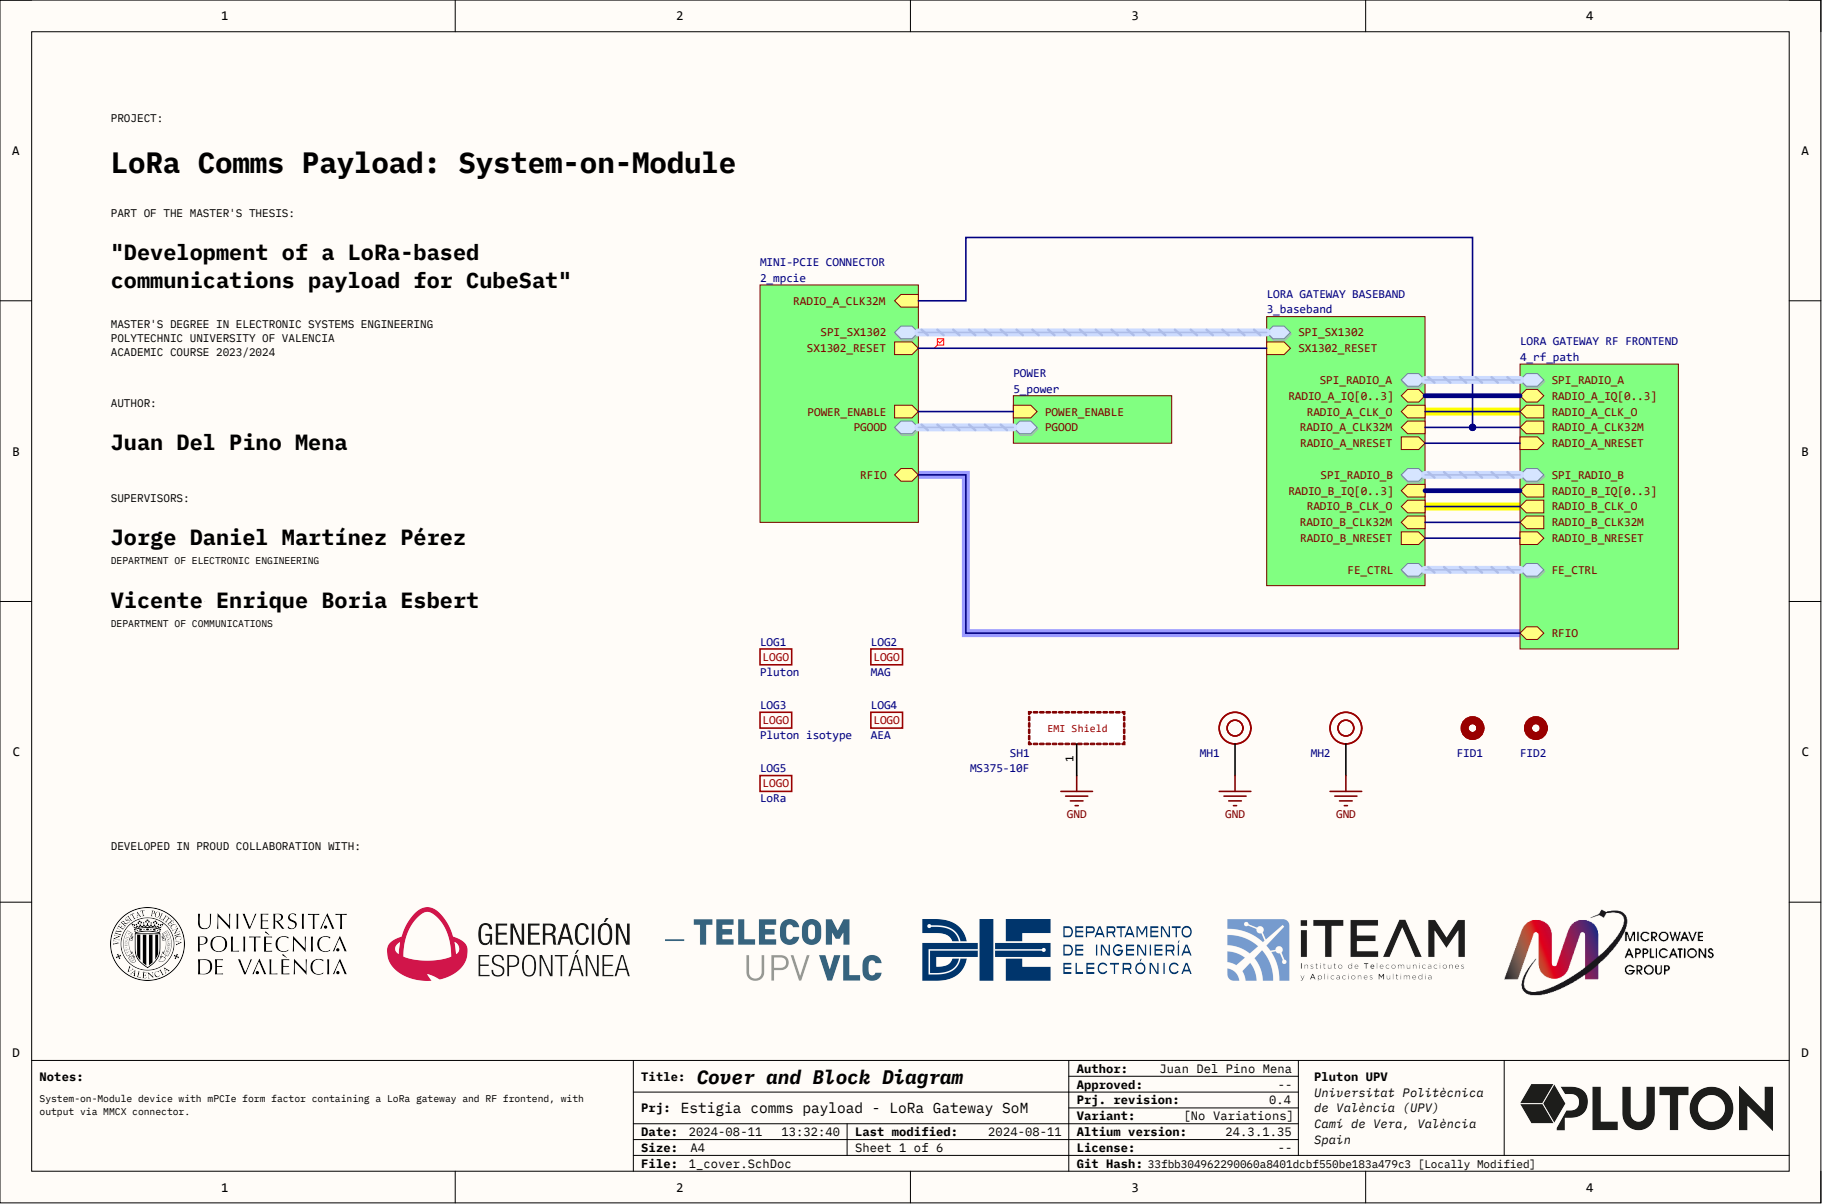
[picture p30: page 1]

RADIO_A_NRESET SPI_RADIO_B

RADIO_B_IQ[0..3] RADIO_B_CLK_O RADIO_B_CLK32M RADIO_B_NRESET FE_CTRL

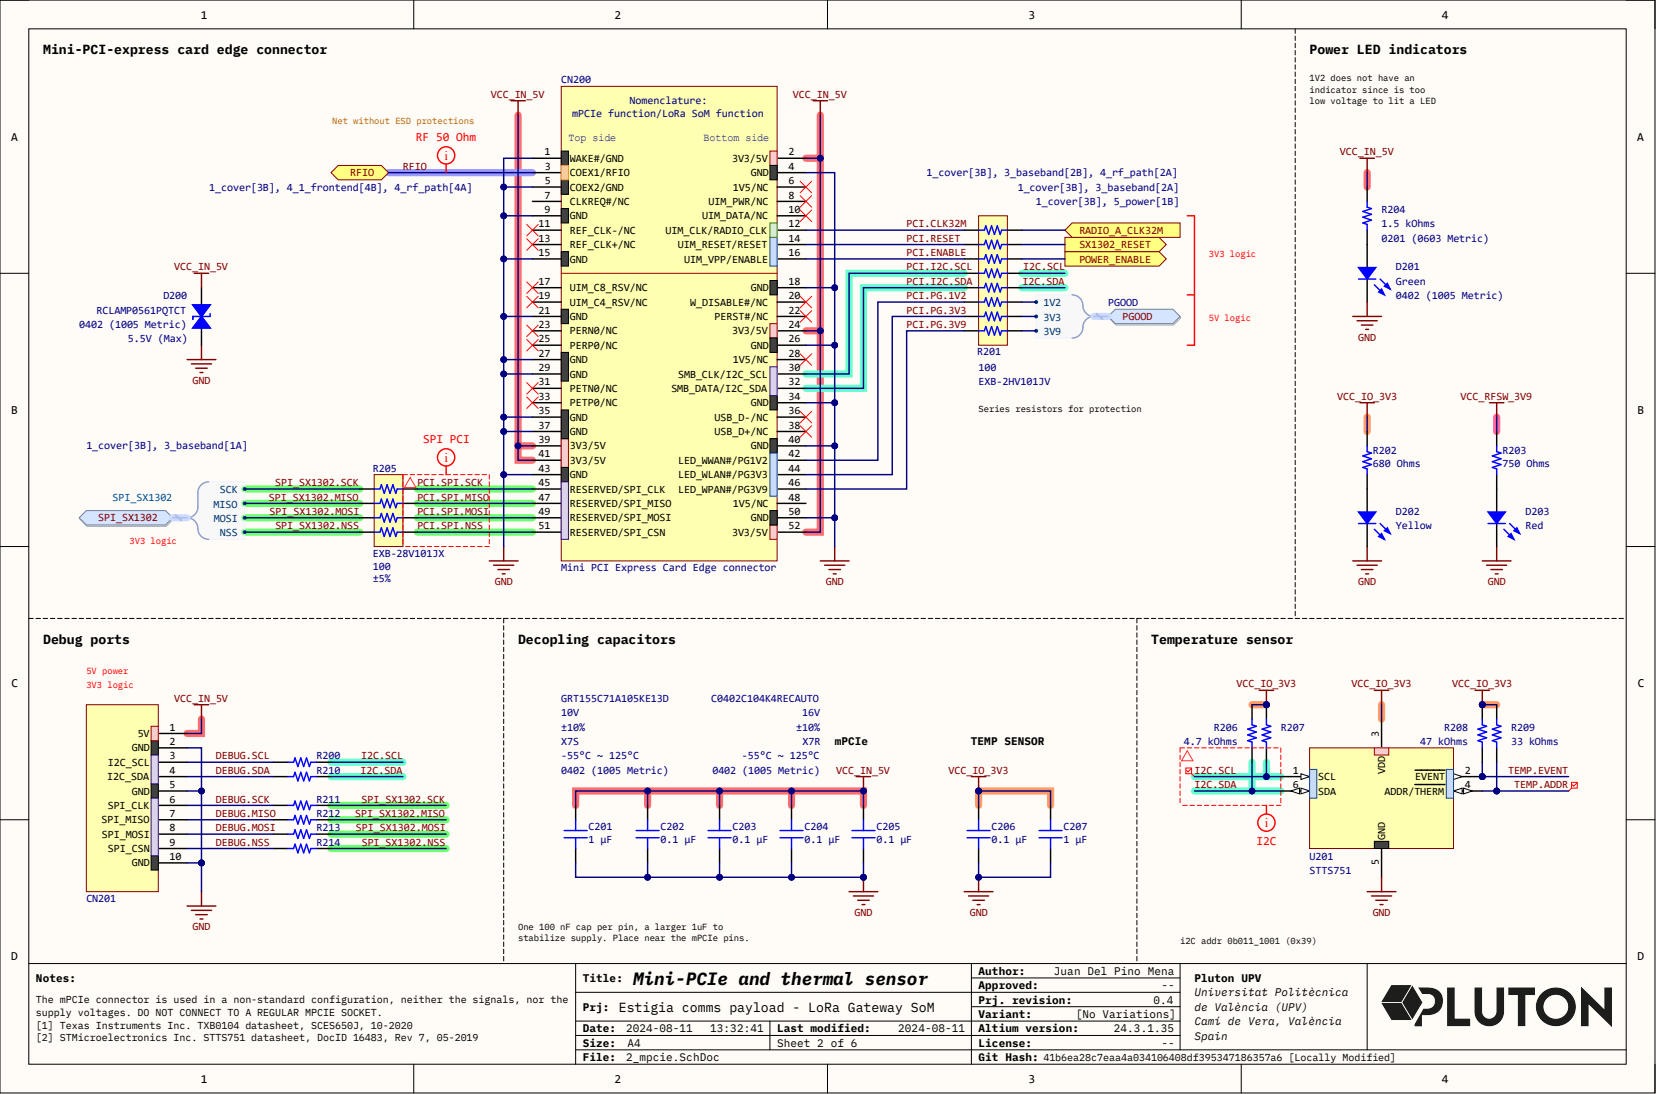
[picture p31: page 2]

Mini-PCI-express card edge connector

1V2 does not have an
indicator since is too
low voltage to lit a LED

Net without ESD protections

mPCIe function/LoRa SoM function

REF_CLK-/NC 11

PCI.ENABLE
PCI.I2C.SCL

PCI.PG.3V3

PERN0/NC 23 | PCI.PG.3V9

Series resistors for protection

GND 37

PCI.SPI.MISO | RESERVED/SPI_MISO 47
PCI.SPI.MOSI | RESERVED/SPI_MOSI 49
PCI.SPI.NSS

Mini PCI Express Card Edge connector

One 100 nF cap per pin, a larger 1uF to
stabilize supply. Place near the mPCIe pins.

Juan Del Pino Mena

The mPCIe connector is used in a non-standard configuration, neither the signals, nor the
supply voltages. DO NOT CONNECT TO A REGULAR MPCIE SOCKET.
[1] Texas Instruments Inc. TXB0104 datasheet, SCES650J, 10-2020
[2] STMicroelectronics Inc. STTS751 datasheet, DocID 16483, Rev 7, 05-2019

Prj: Estigia comms payload - LoRa Gateway SoM

License:
Git Hash: 41b6ea28c7eaa4a034106408df395347186357a6 [Locally Modified]

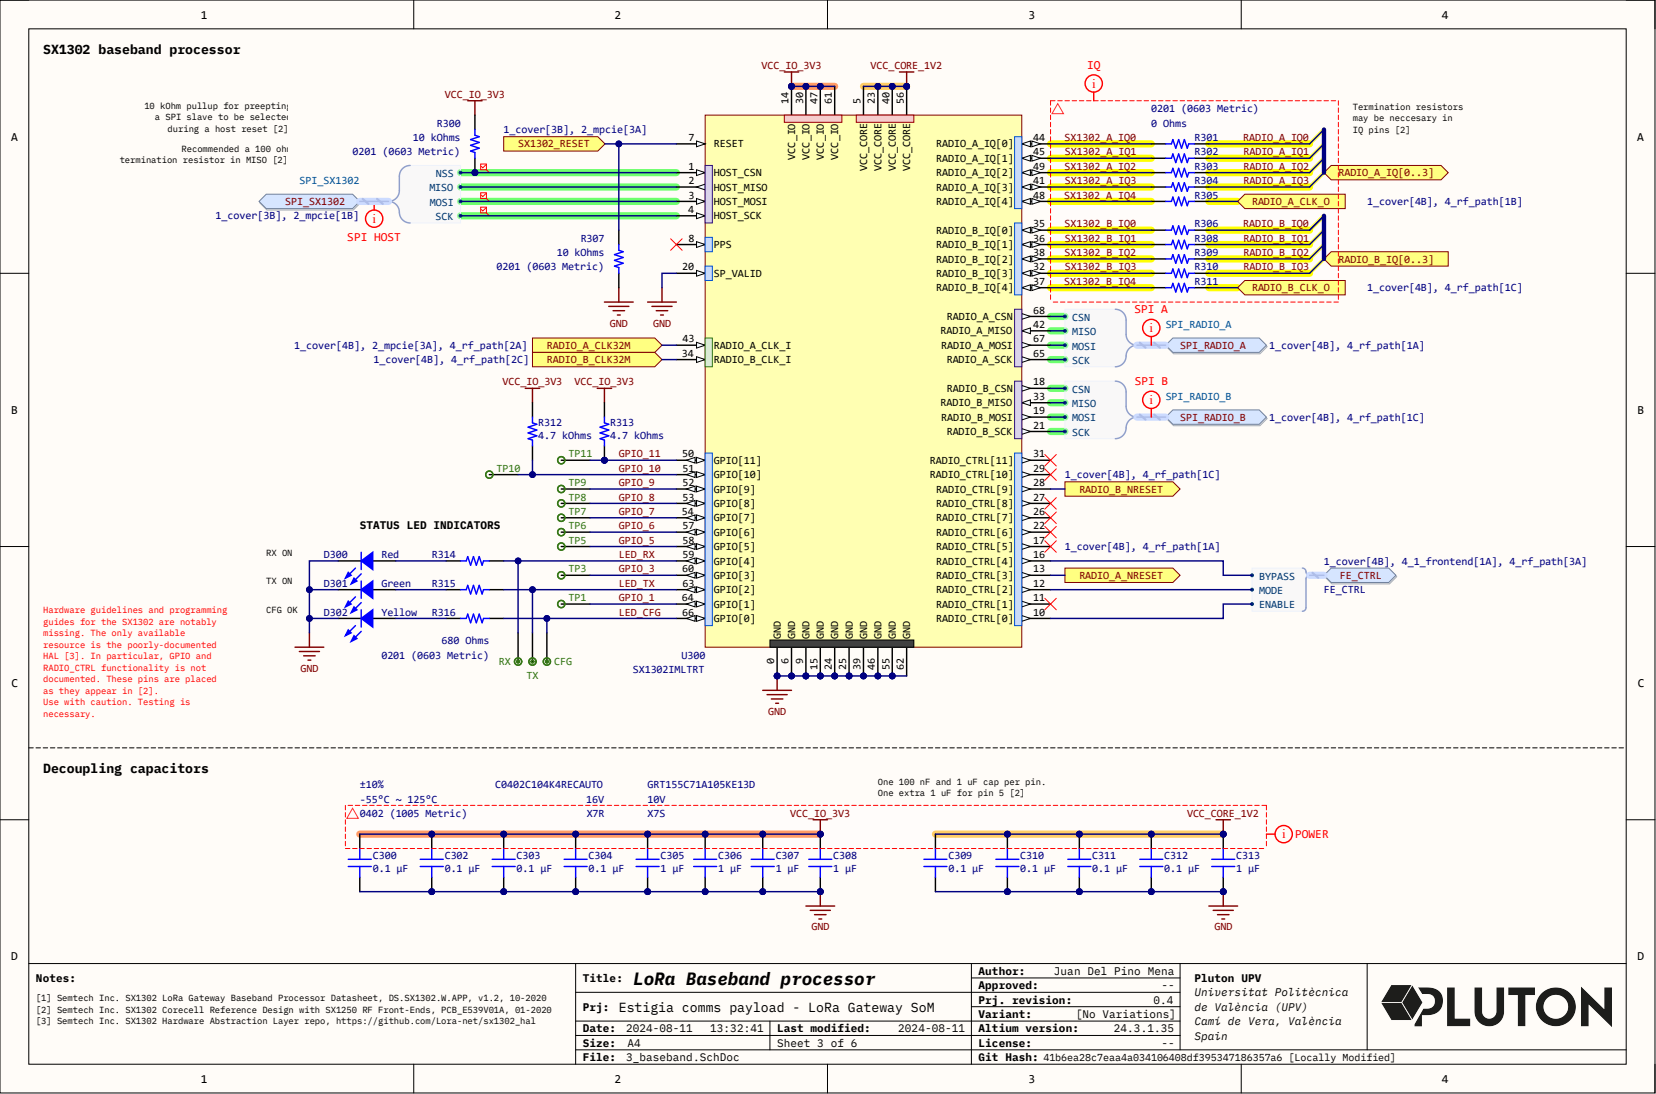
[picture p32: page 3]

10 kOhm pullup for preepting
a SPI slave to be selected
during a host reset [2]

Termination resistors
may be neccesary in

termination resistor in MISO [2]

Hardware guidelines and programming
guides for the SX1302 are notably
missing. The only available
resource is the poorly-documented
HAL [3]. In particular, GPIO and
RADIO_CTRL functionality is not
documented. These pins are placed

as they appear in [2].
Use with caution. Testing is
necessary.

One 100 nF and 1 uF cap per pin.
One extra 1 uF for pin 5 [2]

Juan Del Pino Mena

[1] Semtech Inc. SX1302 LoRa Gateway Baseband Processor Datasheet, DS.SX1302.W.APP, v1.2, 10-2020
[2] Semtech Inc. SX1302 Corecell Reference Design with SX1250 RF Front-Ends, PCB_E539V01A, 01-2020
[3] Semtech Inc. SX1302 Hardware Abstraction Layer repo, https://github.com/Lora-net/sx1302_hal

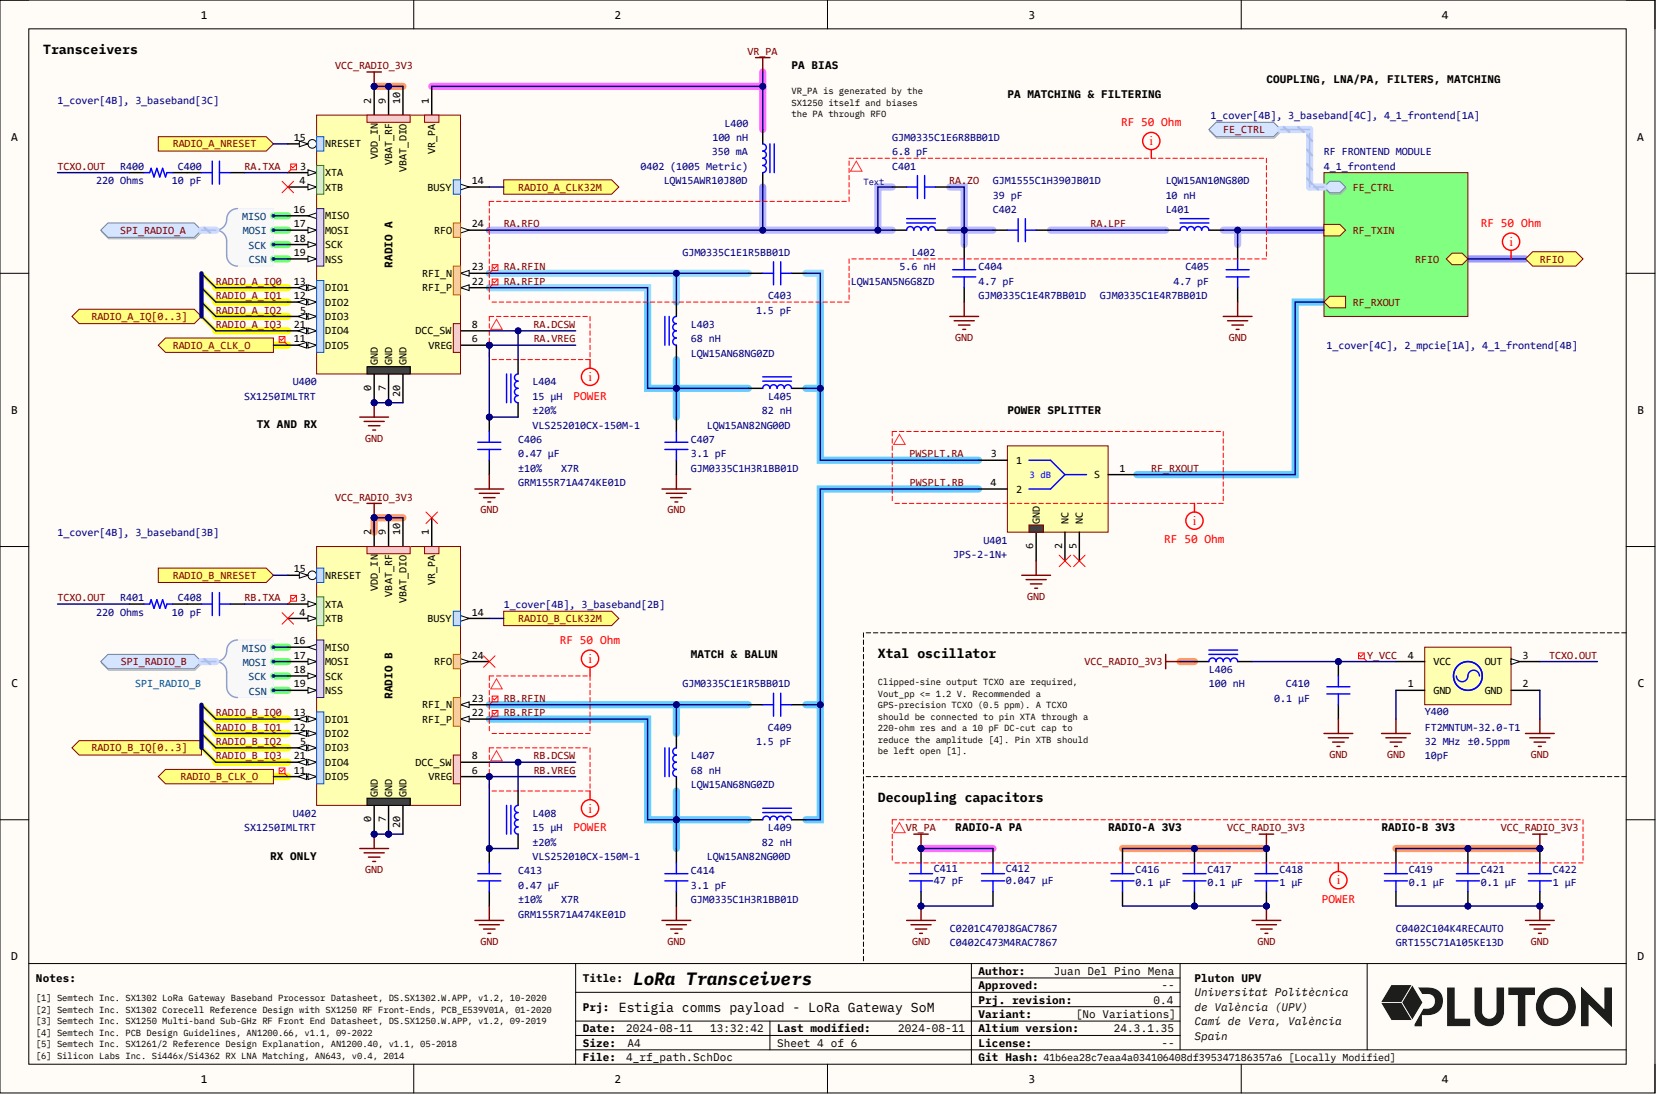
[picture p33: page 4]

RA.RFIP

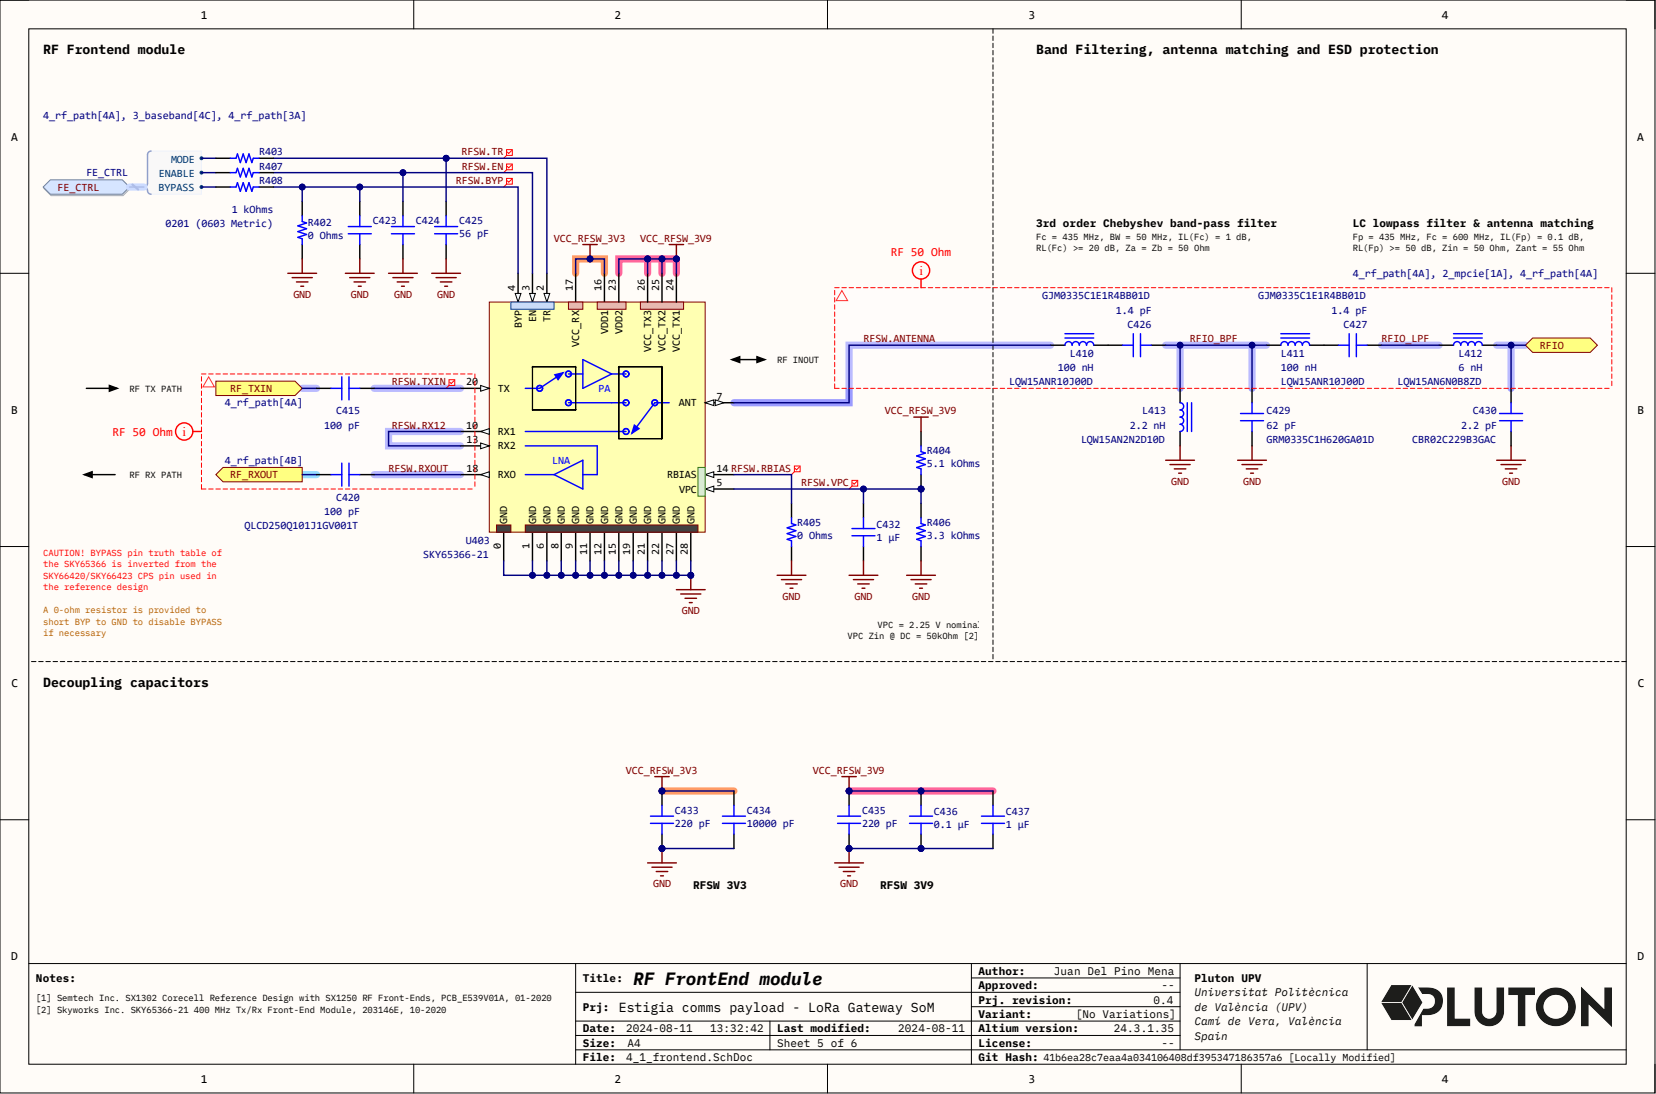
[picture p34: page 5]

Band Filtering, antenna matching and ESD protection

Fc = 435 MHz, BW = 50 MHz, IL(Fc) = 1 dB,
RL(Fc) >= 20 dB, Za = Zb = 50 Ohm

Fp = 435 MHz, Fc = 600 MHz, IL(Fp) = 0.1 dB,
RL(Fp) >= 50 dB, Zin = 50 Ohm, Zant = 55 Ohm

GJM0335C1E1R4BB01D 1.4 pF C426 | GJM0335C1E1R4BB01D 1.4 pF C427

4_rf_path[4A] | RFSW.TXIN

CAUTION! BYPASS pin truth table of
the SKY65366 is inverted from the
SKY66420/SKY66423 CPS pin used in
the reference design

A 0-ohm resistor is provided to
short BYP to GND to disable BYPASS
if necessary

Juan Del Pino Mena

[1] Semtech Inc. SX1302 Corecell Reference Design with SX1250 RF Front-Ends, PCB_E539V01A, 01-2020
[2] Skyworks Inc. SKY65366-21 400 MHz Tx/Rx Front-End Module, 203146E, 10-2020

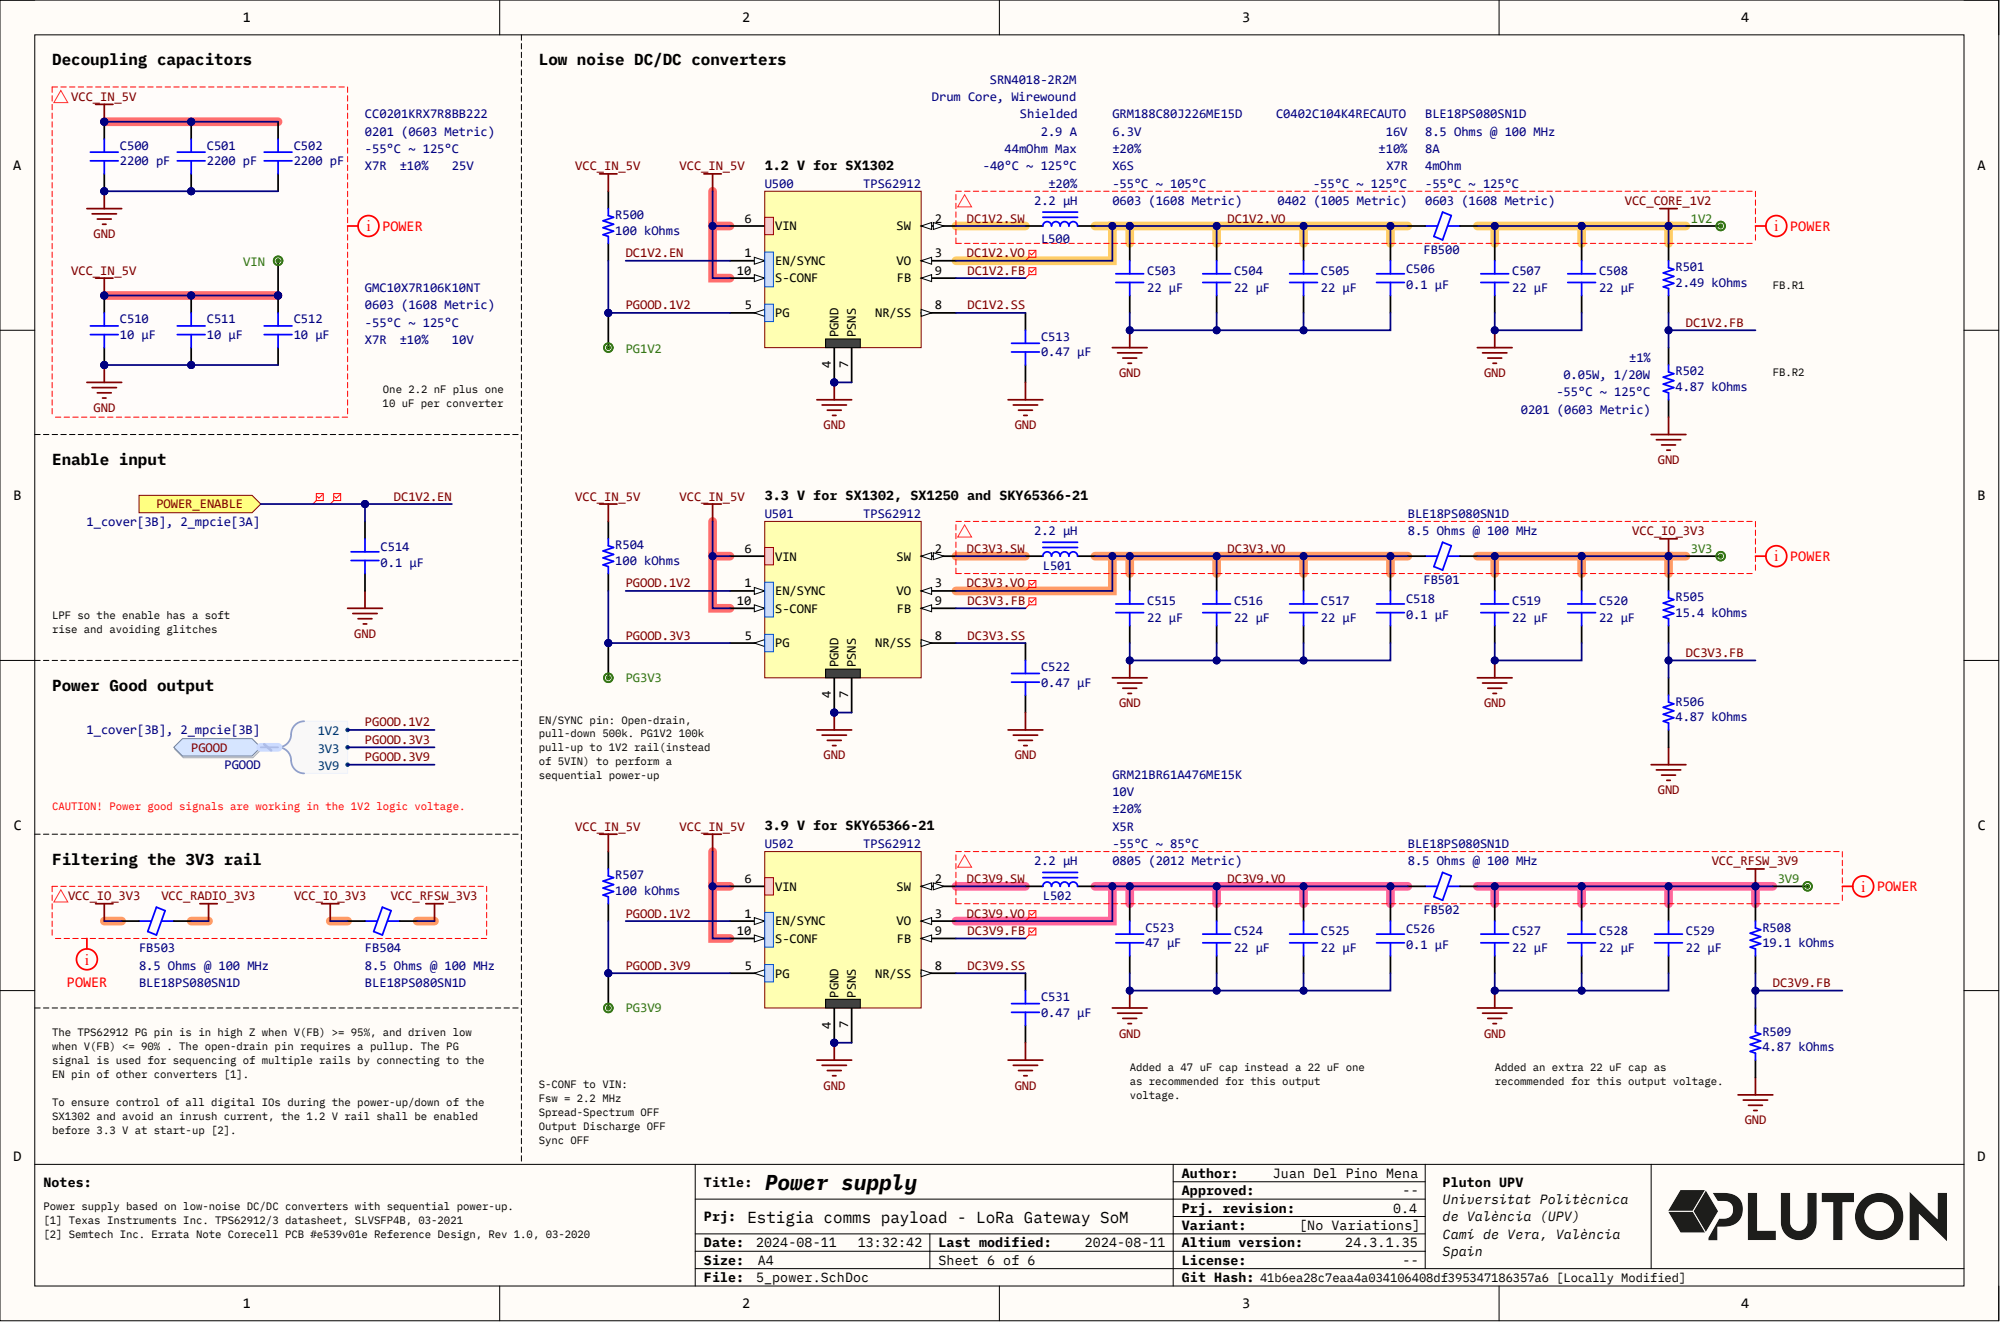
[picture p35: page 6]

PGOOD.1V2 | | DC1V2.FB

PGOOD.3V3 | | DC3V3.FB

PGOOD.3V9 | | DC3V9.FB

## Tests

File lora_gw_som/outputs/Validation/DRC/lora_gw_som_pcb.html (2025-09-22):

Altium

# Design Rule Verification Report

Date: | | 24/07/2024
Time: | | 13:06:23
Elapsed Time: | | 00:00:02
Filename: | | D:\TFM\Dev\Hardware\Altium\lora_gw_som\pcb\lora_gw_som_pcb.PcbDoc

Warnings: | | 0
Rule Violations: | | 0
Waived Violations: | | 7

## Summary

Warnings | Count
Total | 0

Rule Violations | Count
Clearance Constraint (Gap=0.2mm) (InNetClass('RF50')),(All) | 0
Clearance Constraint (Gap=0.125mm) (All),(All) | 0
Clearance Constraint (Gap=0.25mm) (InNet('RFIO')),(All) | 0
Clearance Constraint (Gap=0.15mm) (IsStitchingVia and InNet('GND')),((IsVia and (Not IsStitchingVia)) Or IsPad) | 0
Short-Circuit Constraint (Allowed=No) (All),(All) | 0
Un-Routed Net Constraint ( (All) ) | 0
Modified Polygon (Allow modified: No), (Allow shelved: No) | 0
Width Constraint (Min=0.2mm) (Max=0.5mm) (Preferred=0.4mm) (InNet('VCC_CORE_1V2')) | 0
Width Constraint (Min=0.104mm) (Max=0.227mm) (Preferred=0.227mm) (InNetClass('RF50')) | 0
Width Constraint (Min=0.15mm) (Max=2mm) (Preferred=0.15mm) (All) | 0
Width Constraint (Min=0.2mm) (Max=2mm) (Preferred=0.4mm) (InNetClass('POWER')) | 0
Width Constraint (Min=0.2mm) (Max=0.5mm) (Preferred=0.4mm) (InNet('VCC_IO_3V3')) | 0
Power Plane Connect Rule(Direct Connect )(Expansion=0.2mm) (Conductor Width=0.2mm) (Air Gap=0.2mm) (Entries=4) (All) | 0
Hole Size Constraint (Min=0.2mm) (Max=6mm) (All) | 0
Hole To Hole Clearance (Gap=0.25mm) (All),(All) | 0
Minimum Solder Mask Sliver (Gap=0.01mm) (All),(All) | 0
Silk To Solder Mask (Clearance=0.06mm) (IsPad),(All) | 0
Silk to Silk (Clearance=0mm) (All),(All) | 0
Net Antennae (Tolerance=0mm) (All) | 0
Board Clearance Constraint (Gap=0mm) (InComponent('MH1') Or InComponent('MH2') Or InComponent('SH1')) | 0
Board Clearance Constraint (Gap=0mm) (All) | 0
Board Clearance Constraint (Gap=0mm) (WithinRoom('layers_room')) | 0
Board Clearance Constraint (Gap=0mm) (InNet('EARTH')) | 0
Matched Lengths(Tolerance=20mm) (InNetClass('SPI B')) | 0
Matched Lengths(Tolerance=20mm) (InNetClass('SPI A')) | 0
Matched Lengths(Tolerance=20mm) (InNetClass('SPI HOST')) | 0
Matched Lengths(Tolerance=1.2mm) (InNetClass('ETH')) | 0
Matched Lengths(Tolerance=20mm) (InNetClass('SPI PCI')) | 0
Matched Lengths(Tolerance=15.2mm) (InNetClass('GETH')) | 0
Matched Lengths(Tolerance=20mm) (InNetClass('IQ')) | 0
Matched Lengths(Tolerance=1.2mm) (InDifferentialPairClass('Diff_100ohm')) | 0
Matched Lengths(Tolerance=20mm) (InNetClass('I2C')) | 0
Matched Lengths(Tolerance=20mm) (InNetClass('IQ')) | 0
Matched Lengths(Tolerance=1.2mm) (InDifferentialPairClass('Diff_90ohm')) | 0
Height Constraint (Min=0mm) (Max=25.4mm) (Prefered=12.7mm) (All) | 0
Total | 0

Waived Violations | Count
Un-Routed Net Constraint ( (All) ) | 1
Board Clearance Constraint (Gap=0mm) (All) | 6
Total | 7

## Rule Violations

## Waived Violations

Un-Routed Net Constraint ( (All) )

Un-Routed Net Constraint: Arc (3.833mm,46.519mm) on Bottom Dead Copper - Net Not Assigned.
Waived by Juan del Pino Mena at 16/07/2024 10:59:31
dead copper not important

Back to top

Board Clearance Constraint (Gap=0mm) (All)

Board Outline Clearance(Outline Edge): (Collision < 0.2mm) Between Board Edge And Text "'.Layer_Name'" (132mm,-54.101mm) on Bottom
Waived by Juan del Pino Mena at 23/07/2024 14:03:25
Intentional, layer names

Board Outline Clearance(Outline Edge): (Collision < 0.2mm) Between Board Edge And Text "'.Layer_Name'" (132mm,-54.101mm) on Top
Waived by Juan del Pino Mena at 23/07/2024 14:03:25
Intentional, layer names

Board Outline Clearance(Outline Edge): (Collision < 0.2mm) Between Board Edge And Text "'.Layer_Name'" (132mm,-54.129mm) on Board Layer Stack Bottom Overlay
Waived by Juan del Pino Mena at 23/07/2024 14:03:25
Intentional, layer names

Board Outline Clearance(Outline Edge): (Collision < 0.2mm) Between Board Edge And Text "'.Layer_Name'" (132mm,-54.129mm) on Signal-1
Waived by Juan del Pino Mena at 23/07/2024 14:03:25
Intentional, layer names

Board Outline Clearance(Outline Edge): (Collision < 0.2mm) Between Board Edge And Text "'.Layer_Name'" (132mm,-54.129mm) on Signal-2
Waived by Juan del Pino Mena at 23/07/2024 14:03:25
Intentional, layer names

Board Outline Clearance(Outline Edge): (Collision < 0.2mm) Between Board Edge And Text "'.Layer_Name'" (132mm,-54.129mm) on Top Overlay
Waived by Juan del Pino Mena at 23/07/2024 14:03:25
Intentional, layer names

Back to top

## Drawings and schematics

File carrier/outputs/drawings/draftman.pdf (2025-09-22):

1 | 1

## Transmission Line Structure Table

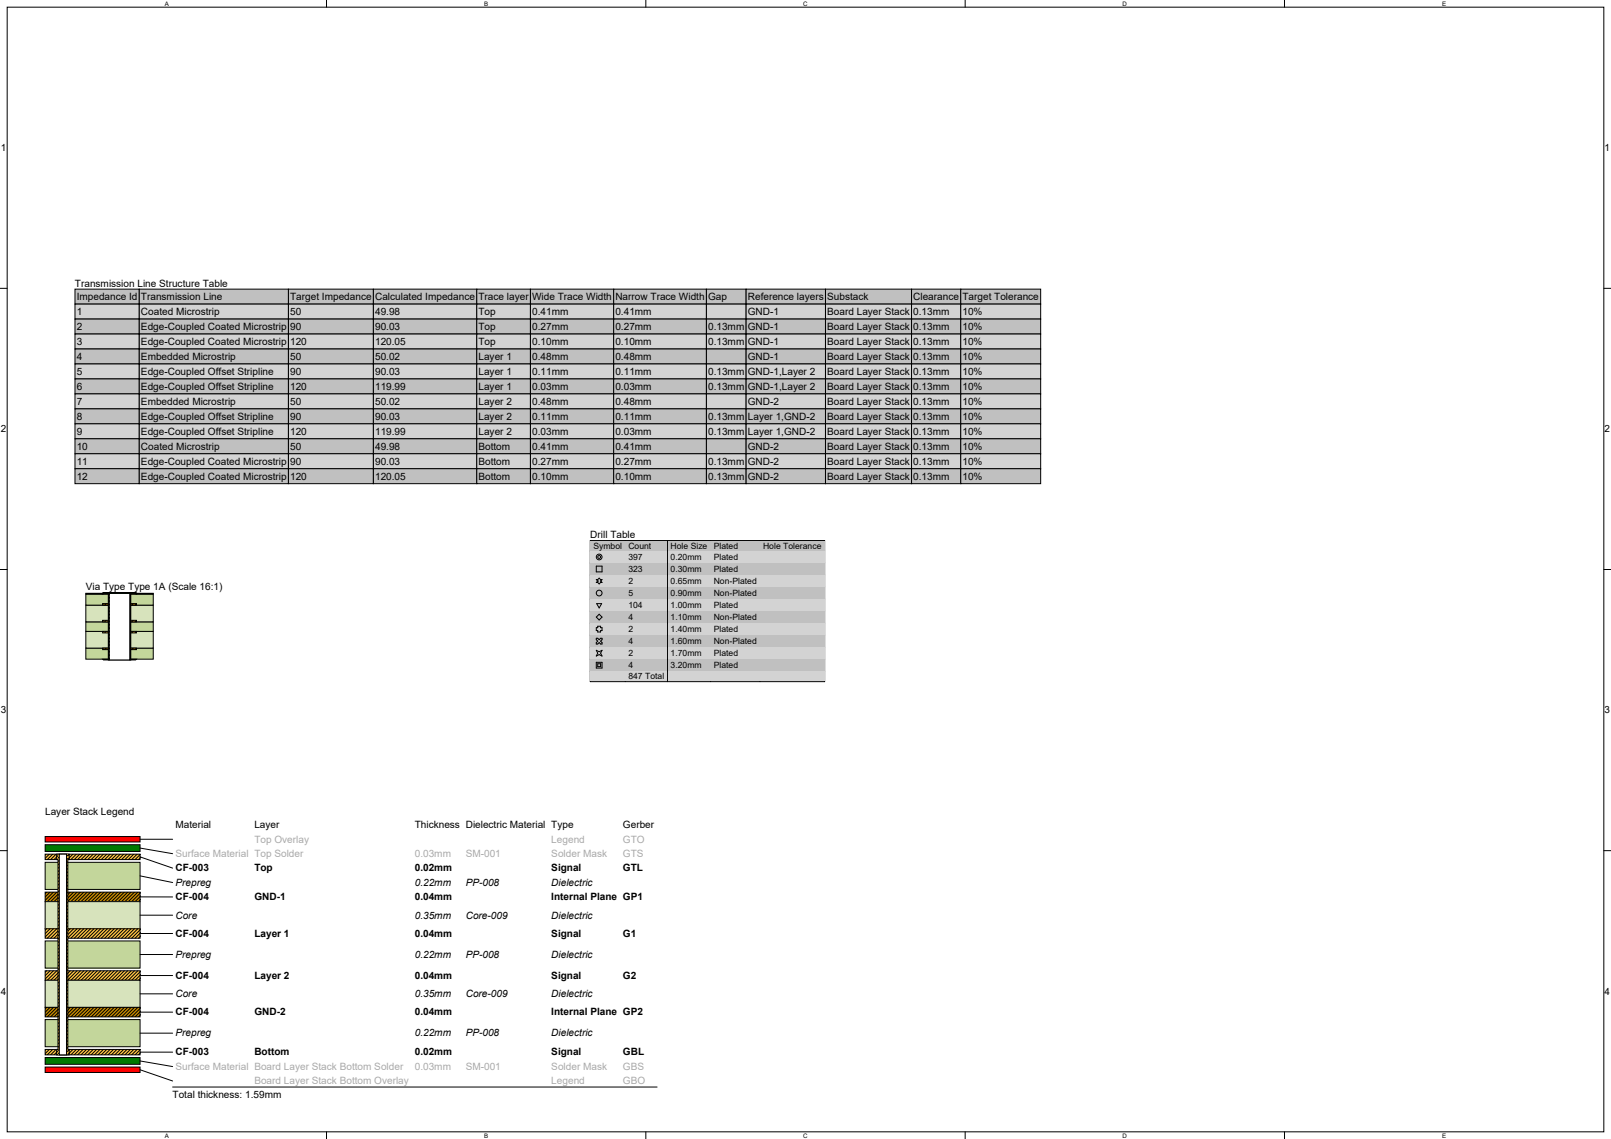
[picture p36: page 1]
Material; Layer; Thickness Dielectric Material Type; Gerber; Top Overlay; Legend; GTO; Surface Material Top Solder; Solder Mask; GTS; Top; Signal; GTL; Prepreg; Dielectric; GND-1; Internal Plane GP1; Core; Core-009; Layer 1; Layer 2; GND-2; Internal Plane GP2; Bottom; GBL; Surface Material Board Layer Stack Bottom Solder 0.03mm; GBS; Board Layer Stack Bottom Overlay; GBO; Total thickness: 1.59mm; Impedance Id 1 2 3 4 5 6 7 8 9 10 11 12; Target Impedance 50 90 120 50 90 120 50 90 120 50 90 120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

Transmission Line
Coated Microstrip
Edge-Coupled Coated Microstrip
Embedded Microstrip
Edge-Coupled Offset Stripline

Substack
Board Layer Stack

Symbol | Count | Hole Size | Plated | Hole Tolerance

397 | 0.20mm | Plated
323 | 0.30mm | Plated
2 | 0.65mm | Non-Plated
5 | 0.90mm | Non-Plated
104 | 1.00mm | Plated
4 | 1.10mm | Non-Plated
2 | 1.40mm | Plated
4 | 1.60mm | Non-Plated
2 | 1.70mm | Plated
4 | 3.20mm | Plated
847 Total

Via Type Type 1A (Scale 16:1)

Layer Stack Legend

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
Line # | Designator | | manufacturer | Operating Temperature | Package / Case | Part Number | Tolerance | Value | price | Supplier 1
| ANT500 | Quantity 1216
| C200, C201 | | Murata Electronics | -55°C ~ 125°C | 0201 (0603 Metric) | GRM0335C1E221JA01D | ±5% | 220 pF | 0.01 | DigiKey
| C202 | | Murata Electronics | -55°C ~ 85°C | 0805 (2012 Metric) | GRM21BR61A476ME15K | ±20% | 47 µF | 0.13 | DigiKey
| C203, C301, C303, C403, C406, C708 | | Murata Electronics | -55°C ~ 125°C | 0402 (1005 Metric) | GRT155C71A105KE13D | ±10% | 1 µF | 0.04 | DigiKey
| C204, C205, C206, C207, C208, C209, C210, C211, C212, C300, C302, C400, C404, C407, C408, C409, C410, C411, C501, C502, C603, C606, C611, C613, C614, C704, C705, C706, C707, C709, C710, C800, C801, C802, C803, C804 | | KEMET | -55°C ~ 125°C | 0402 (1005 Metric) | C0402C104K4RECAUTO | ±10% | 0.1 µF | 0.01 | DigiKey
| C401, C402 | | KEMET | -55°C ~ 125°C | 0201 (0603 Metric) | CBR02C120F3GAC | ±1% | 12 pF | 0.07 | DigiKey
| C405, C503 | | Murata Electronics | -55°C ~ 125°C | 0402 (1005 Metric) | GRM1555C1E103JE01J | ±5% | 10000 pF | 0.02 | DigiKey
| C412, C805 | | Murata Electronics | -55°C ~ 125°C | 0603 (1608 Metric) | GRM188Z71C475KE21J | ±10% | 4.7 µF | 0.04 | DigiKey
| C500, C504, C505 | | KEMET | -55°C ~ 125°C | 0402 (1005 Metric) | CBR04C101J3GAC | ±5% | 100 pF | 0.02 | DigiKey
| C600, C601, C602, C604, C605, C608, C609, C610 | 3622238242221122111111 | TDK Corporation | -55°C ~ 125°C | 0805 (2012 Metric) | C2012X7S1A226M125AC | ±20% | 22 µF | 0.23 | DigiKey
| C607, C612 | | TDK Corporation | -55°C ~ 125°C | 0402 (1005 Metric) | CGA2B1X7S1C474K050BC | ±10% | 0.47 µF | 0.03 | DigiKey
| C615, C616, C618, C619 | | TDK Corporation | -55°C ~ 125°C | 0805 (2012 Metric) | C2012X7S1E106K125AC | ±10% | 10 µF | 0.11 | DigiKey
| C617, C620 | | Yageo | -55°C ~ 125°C | 0201 (0603 Metric) | CC0201KRX7R8BB222 | ±10% | 2200 pF | 0.01 | DigiKey
| C700, C702 | | Murata Electronics | -55°C ~ 125°C | 0402 (1005 Metric) | GRM1557U1A332JA01D | ±5% | 3300 pF | 0.01 | DigiKey
| C701, C703 | | KEMET | -55°C ~ 125°C | 0402 (1005 Metric) | C0402C222J8JAC7867 | ±5% | 2200 pF | 0.02 | DigiKey
| CN200
| CN201
| CN300, CN301
| CN302, CN303
| CN800
| CN803
| D200 | | Semtech Corporation | -40°C ~ 125°C (TJ) | 0402 (1005 Metric) | RCLAMP0561PQTCT | | | 0.13 | DigiKey
| D500 | | Murata Electronics | -40°C ~ 85°C (TA) | 0402 (1005 Metric) | LXES15AAA1-153 | | | 0.04 | DigiKey
| D600 | | Everlight Electronics Co Ltd | | 0402 (1005 Metric) | EAST10052GA0 | | Green | 0.09 | DigiKey
| D601 | | Stanley Electric Co | | 0402 (1005 Metric) | FHY1105P-TR | | Yellow | 0.05 | DigiKey
| D800, D801, D802, D803, D804, D805, D806, D807, D808, D809 | | Nexperia USA Inc. | -65°C ~ 150°C (TA) | SC-76, SOD-323 | PESD3V3L1BA,115 | | | 0.06 | DigiKey
| FB500, FB600, FB800 | | Murata Electronics | -55°C ~ 125°C | 0603 (1608 Metric) | BLE18PS080SN1D | | 8.5 Ohms @ 100 MHz | 0.08 | DigiKey
| L400 | | TDK Electronics Inc. | -55°C ~ 150°C | 0603 (1608 Metric) | B82496C3101J000 | ±5% | 100nH | 0.16 | DigiKey
| L600, L601 | 1031212927 | Bourns Inc. | -40°C ~ 125°C | Nonstandard | SRN4018-2R2M | ±20% | 2.2 µH | 0.17 | DigiKey
| Q200 | | Diodes Incorporated | -55°C ~ 150°C (TJ) | TO-236-3, SC-59, SOT-23-3 | BSS84-7-F | | | 0.02 | DigiKey
| R200, R204 | | Vishay Dale | -55°C ~ 155°C | 0201 (0603 Metric) | CRCW0201120RFNED | ±1% | 120 Ohms | 0.01 | DigiKey
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

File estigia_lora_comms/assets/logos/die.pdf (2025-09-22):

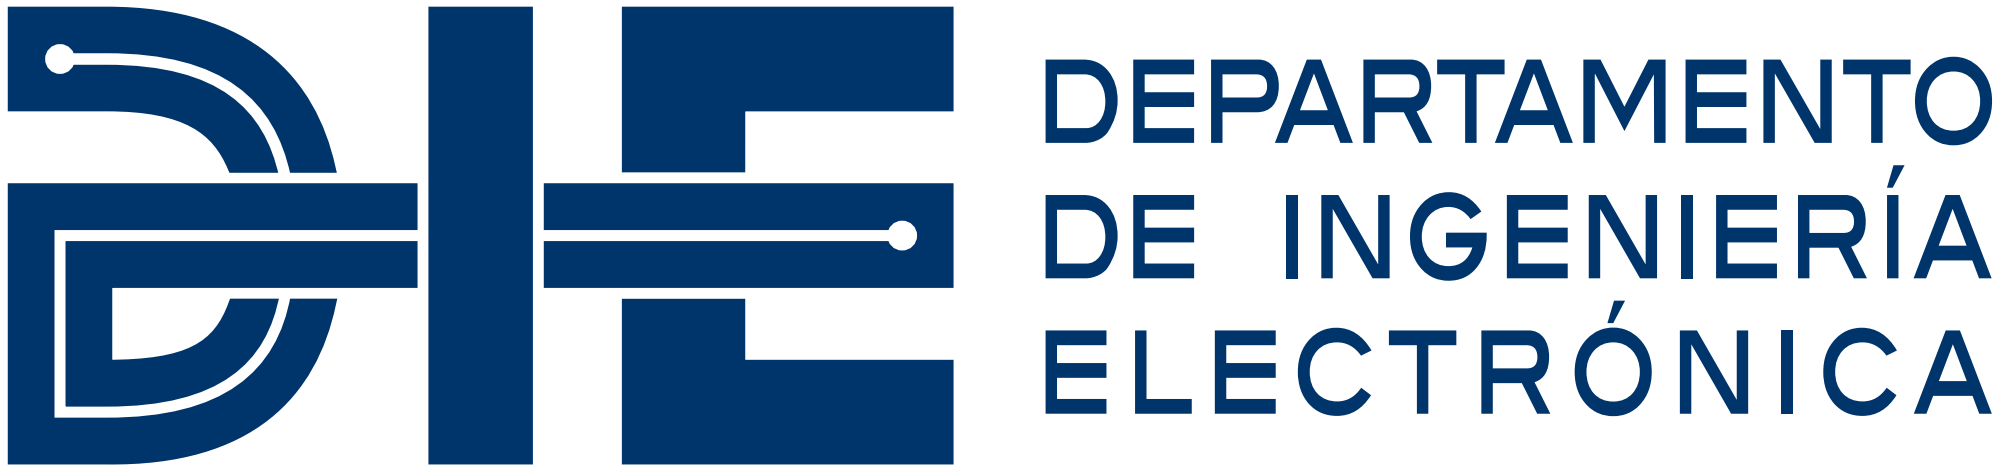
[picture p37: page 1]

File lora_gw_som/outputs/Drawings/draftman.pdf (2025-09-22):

1

1

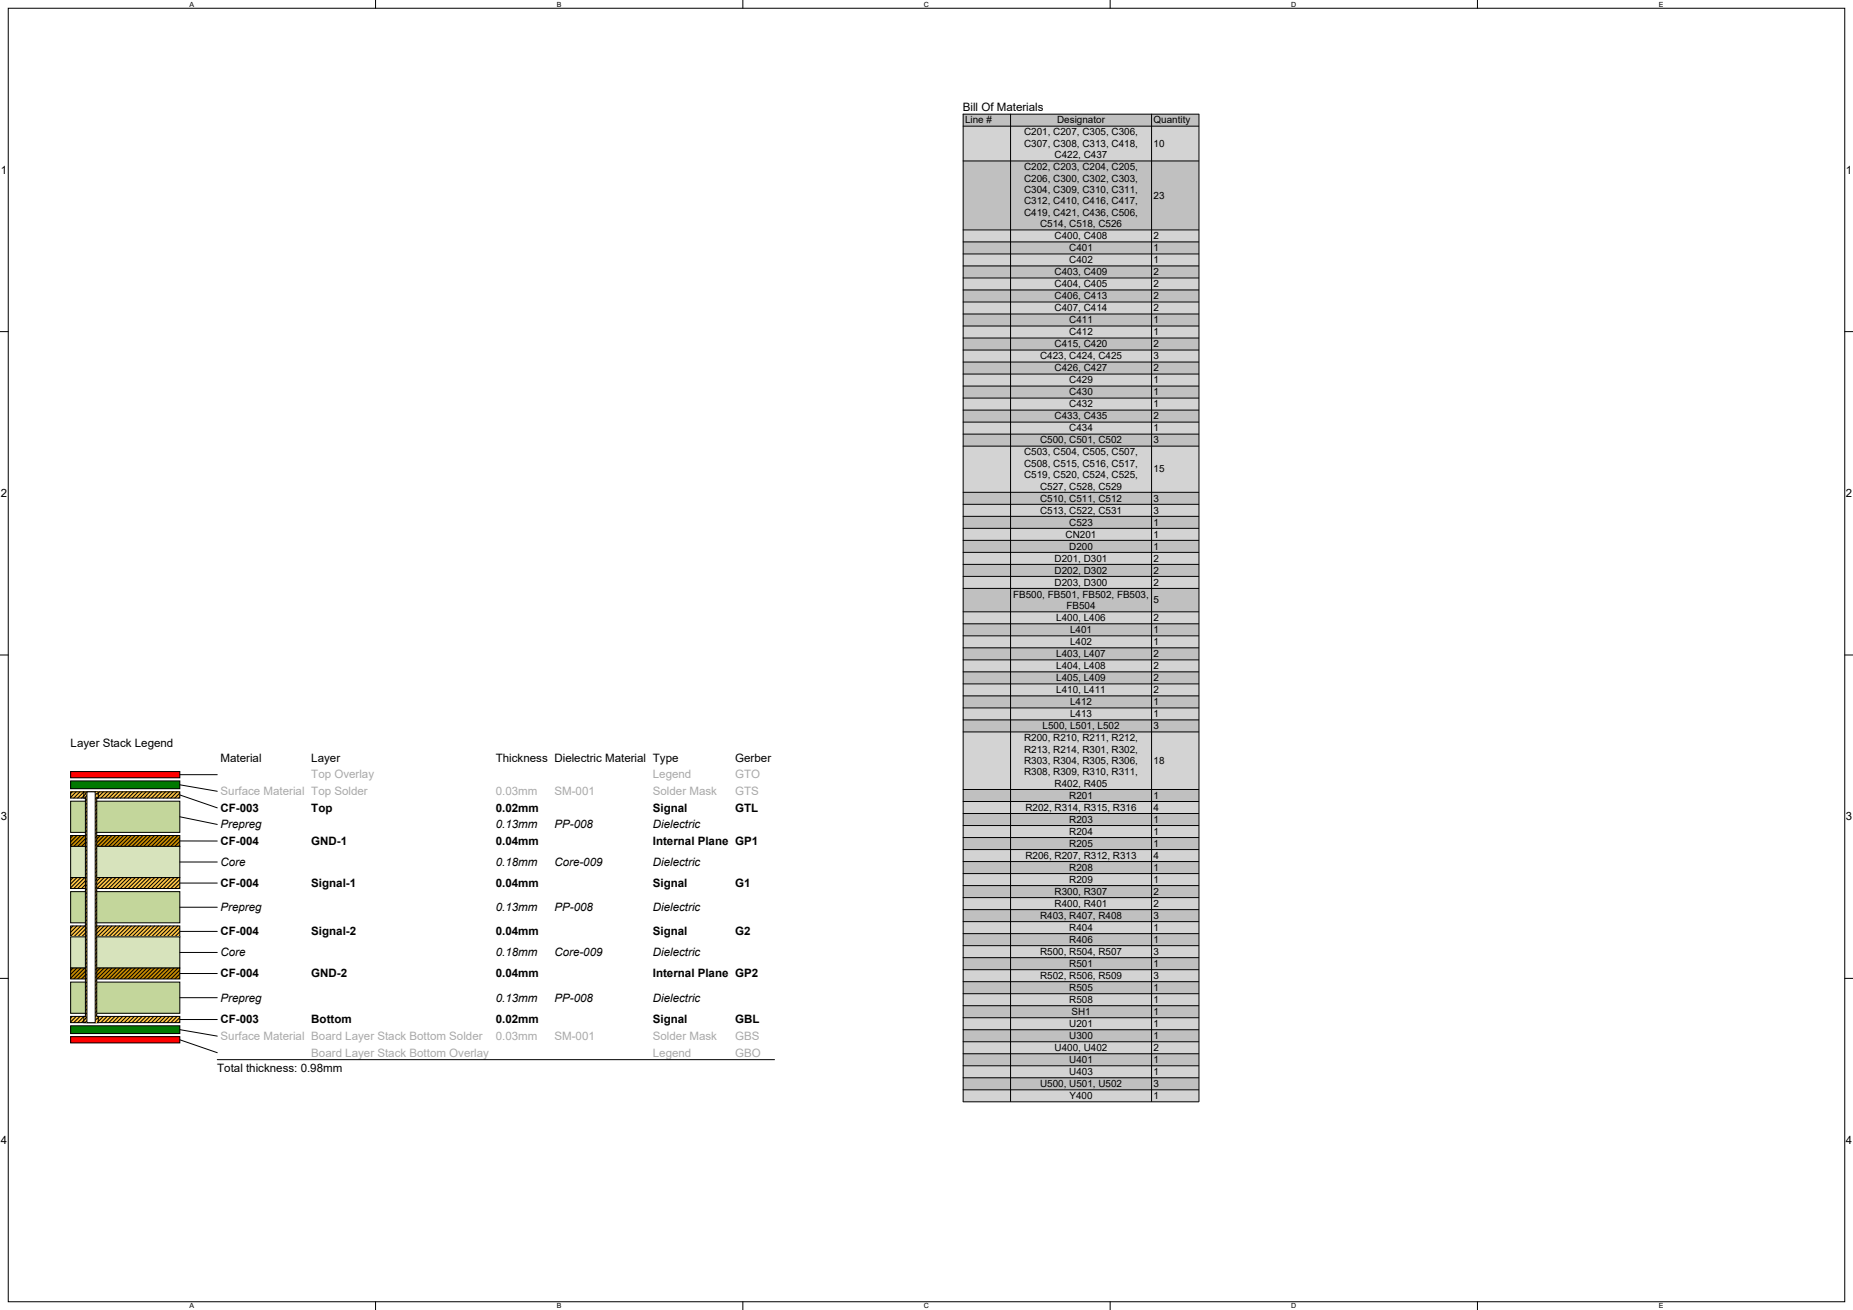
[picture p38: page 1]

Line # | Designator | Quantity

C400, C408
C401
C402

C404, C405
C406, C413
C407, C414
C411
C412
C415, C420
C423, C424, C425
C426, C427
C429
C430
C432
C433, C435
C434
C500, C501, C502
C503, C504, C505, C507, C508, C515, C516, C517, C519, C520, C524, C525, C527, C528, C529
D201, D301 | 153311122252112222113

C510, C511, C512
C513, C522, C531
C523
CN201
D200

D202, D302
D203, D300

L400, L406
L401
L402
L403, L407
L404, L408
L405, L409
L410, L411
L412
L413
L500, L501, L502
R200, R210, R211, R212, R213, R214, R301, R302, R303, R304, R305, R306, R308, R309, R310, R311, R402, R405

R203
R204
R205

R209
R300, R307
R400, R401
R403, R407, R408
R404
R406
R500, R504, R507
R501
R502, R506, R509
R505
R508
SH1
U201
U300
U400, U402
U401
U403
U500, U501, U502
Y400

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
Line # | Designator | Quantity | manufacturer | Operating Temperature | Package / Case | Part Number | Tolerance | Value | price | Supplier 1
| C201, C207, C305, C306, C307, C308, C313, C418, C422, C437 | 10 | Murata Electronics | -55°C ~ 125°C | 0402 (1005 Metric) | GRT155C71A105KE13D | ±10% | 1 µF | 0.04 | DigiKey
| C202, C203, C204, C205, C206, C300, C302, C303, C304, C309, C310, C311, C312, C410, C416, C417, C419, C421, C436, C506, C514, C518, C526 | | KEMET | -55°C ~ 125°C | 0402 (1005 Metric) | C0402C104K4RECAUTO | ±10% | 0.1 µF | 0.01 | DigiKey
| C400, C408 | | Murata Electronics | -55°C ~ 125°C | 0201 (0603 Metric) | GJM0335C1E100GB01D | ±2% | 10 pF | 0.01 | DigiKey
| C401 | | Murata Electronics | -55°C ~ 125°C | 0201 (0603 Metric) | GJM0335C1E6R8BB01D | ±0.1pF | 6.8 pF | 0.01 | DigiKey
| C402 | | Murata Electronics | -55°C ~ 125°C | 0402 (1005 Metric) | GJM1555C1H390JB01D | ±5% | 39 pF | 0.02 | DigiKey
| C403, C409 | | Murata Electronics | -55°C ~ 125°C | 0201 (0603 Metric) | GJM0335C1E1R5BB01D | ±0.1pF | 1.5 pF | 0.01 | DigiKey
| C404, C405 | 23211222211232111213 | Murata Electronics | -55°C ~ 125°C | 0201 (0603 Metric) | GJM0335C1E4R7BB01D | ±0.1pF | 4.7 pF | 0.01 | DigiKey
| C406, C413 | | Murata Electronics | -55°C ~ 125°C | 0402 (1005 Metric) | GRM155R71A474KE01D | ±10% | 0.47 µF | 0.12 | DigiKey
| C407, C414 | | Murata Electronics | -55°C ~ 125°C | 0201 (0603 Metric) | GJM0335C1H3R1BB01D | ±0.1pF | 3.1 pF | 0.01 | DigiKey
| C411 | | KEMET | -55°C ~ 125°C | 0201 (0603 Metric) | C0201C470J8GAC7867 | ±5% | 47 pF | 0.01 | DigiKey
| C412 | | KEMET | -55°C ~ 125°C | 0402 (1005 Metric) | C0402C473M4RAC7867 | ±20% | 0.047 µF | 0.01 | DigiKey
| C415, C420 | | Johanson Technology Inc. | -55°C ~ 125°C | 0201 (0603 Metric) | QLCD250Q101J1GV001T | ±5% | 100 pF | 0.02 | DigiKey
| C423, C424, C425 | | Murata Electronics | -55°C ~ 125°C | 0201 (0603 Metric) | GRM0335C1H560GA01D | ±2% | 56 pF | 0.01 | DigiKey
| C426, C427 | | Murata Electronics | -55°C ~ 125°C | 0201 (0603 Metric) | GJM0335C1E1R4BB01D | ±0.1pF | 1.4 pF | 0.01 | DigiKey
| C429 | | Murata Electronics | -55°C ~ 125°C | 0201 (0603 Metric) | GRM0335C1H620GA01D | ±2% | 62 pF | 0.01 | DigiKey
| C430 | | KEMET | -55°C ~ 125°C | 0201 (0603 Metric) | CBR02C229B3GAC | ±0.1pF | 2.2 pF | 0.02 | DigiKey
| C432 | | Samsung Electro-Mechanics | -55°C ~ 85°C | 0402 (1005 Metric) | CL05A105KO5NNNC | ±10% | 1 µF | 0.01 | DigiKey
| C433, C435 | | Murata Electronics | -55°C ~ 125°C | 0201 (0603 Metric) | GRM0335C1H221JA01D | ±5% | 220 pF | 0.01 | DigiKey
| C434 | | Murata Electronics | -55°C ~ 125°C | 0402 (1005 Metric) | GRM1555C1E103JE01J | ±5% | 10000 pF | 0.02 | DigiKey
| C500, C501, C502 | | Yageo | -55°C ~ 125°C | 0201 (0603 Metric) | CC0201KRX7R8BB222 | ±10% | 2200 pF | 0.01 | DigiKey
| C503, C504, C505, C507, C508, C515, C516, C517, C519, C520, C524, C525, C527, C528, C529 | | Murata Electronics | -55°C ~ 105°C | 0603 (1608 Metric) | GRM188C80J226ME15D | ±20% | 22 µF | 0.03 | DigiKey
| C510, C511, C512 | | Cal-Chip Electronics, Inc. | -55°C ~ 125°C | 0603 (1608 Metric) | GMC10X7R106K10NT | ±10% | 10 µF | 0.26 | DigiKey
| C513, C522, C531 | | TDK Corporation | -55°C ~ 125°C | 0402 (1005 Metric) | CGA2B1X7S1C474K050BC | ±10% | 0.47 µF | 0.03 | DigiKey
| C523 | | Murata Electronics | -55°C ~ 85°C | 0805 (2012 Metric) | GRM21BR61A476ME15K | ±20% | 47 µF | 0.13 | DigiKey
| CN201
| D200 | | Semtech Corporation | -40°C ~ 125°C (TJ) | 0402 (1005 Metric) | RCLAMP0561PQTCT | | | 0.13 | DigiKey
| D201, D301 | 153311122252112222113 | Everlight Electronics Co Ltd | | 0402 (1005 Metric) | EAST10052GA0 | | Green | 0.09 | DigiKey
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
